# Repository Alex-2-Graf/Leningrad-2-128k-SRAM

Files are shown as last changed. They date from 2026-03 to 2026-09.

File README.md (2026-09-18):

# Leningrad-2-128k-SRAM  
  
> [English](README.en.md) | [Русский](README.md)  
  
---
  
## Leningrad-2. Russian ZX Spectrum clone. Schematics and PCB.  
  
После успешного запуска [Leningrad-2-48k](https://github.com/Alex-2-Graf/LENINGRAD-2-48k) и с учётом предложений сообщества  
было принято решение использовать в проекте статическую память вместо динамической.  
Пришлось существенно переделать узел обращения к памяти.  
Заодно было реализовано расширение до 128K без использования внешних плат.  
Также на освободившемся месте удалось разместить два чипа YM2149F,  
тем самым получив «из коробки» Turbo Sound от NedoPC.  
Также был добавлен арбитр IORQ.  
  
В результате на свет появился «Ленинград 2 NEXT 128K + TS 2025».  
  
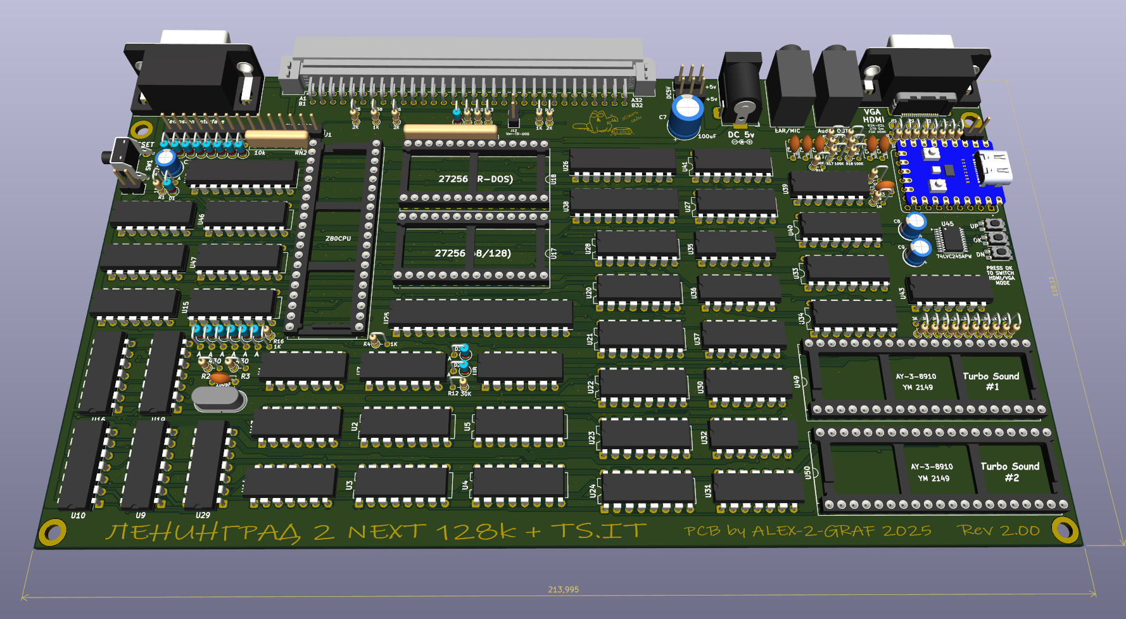
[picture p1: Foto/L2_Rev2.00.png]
  
  
После сборки и отладки были устранены мелкие недостатки.  
Также по настойчивым просьбам друзей проект получил новое название "Аврора".  
  
Свет увидела новая версия [iBOM 2.01](Export/Leningrad%202%20128k%20SRAM%202.01%202025.html)   [Схема](Export/Leningrad%202%20128k%20SRAM%202.01%202025.pdf)   [Gerber](Gerber/Leningrad%202%20128k%20SRAM%202.01%202025%20gerber%20made%20in%20Italy.zip)  
  
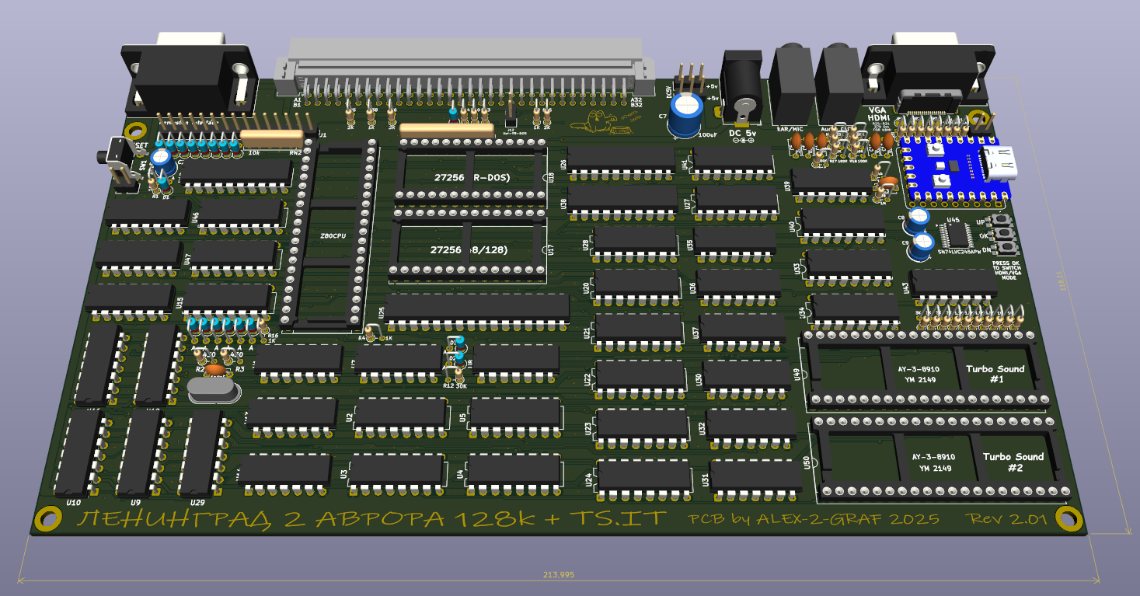
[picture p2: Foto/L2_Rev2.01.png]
  
  
Не обошлось и без курьёза.  
По настойчивой просьбе производителя плат  
пришлось изменить надпись с "Made in" на "Designed in" ;)  
  
После сборки всё заработало без нареканий.  
  
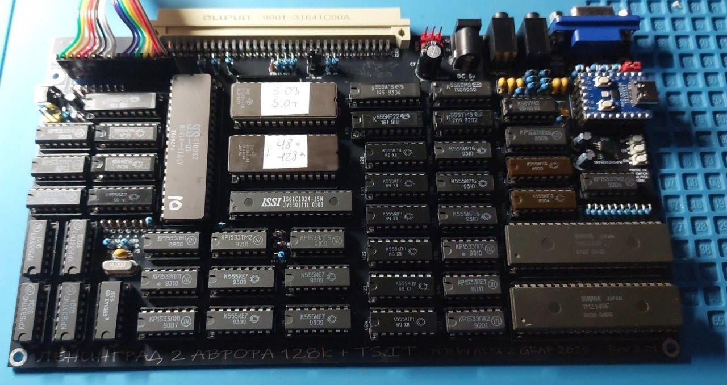
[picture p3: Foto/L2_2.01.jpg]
  
  
Перед выпуском следующей версии были добавлены индикатор питания и исправлен порт джойстика.  
В производство отправилась версия [iBOM 2.02](Export/Leningrad%202%20128k%20SRAM%202.02%202025.html)   [Схема](Export/Leningrad%202%20128k%20SRAM%202.02%202025.pdf)   [Gerber](Gerber/Leningrad%202%20128k%20SRAM%202.02%202025%20Gerber.zip)  
  
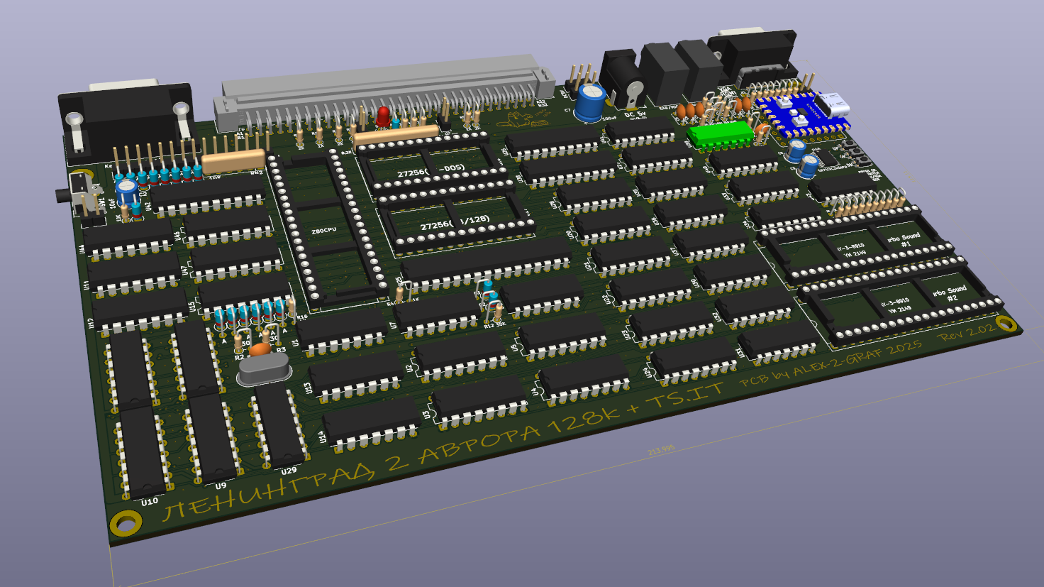
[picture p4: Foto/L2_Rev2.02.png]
  
  
Также был выпущен переходник на Немо и ZX-bus [Gerber](Gerber/L2_NS_Rev_1_1_Gerber.zip)  
  
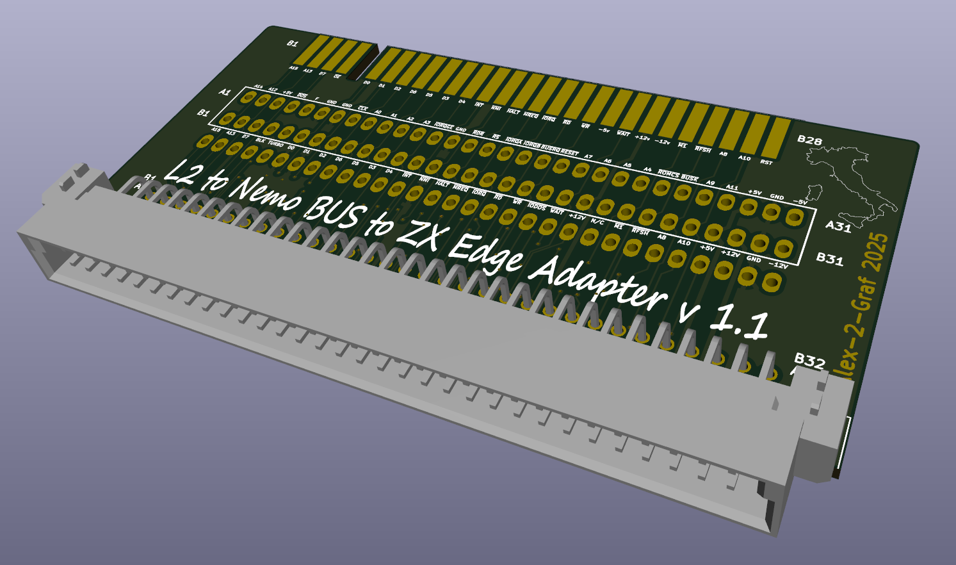
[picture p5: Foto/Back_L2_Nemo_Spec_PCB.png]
  
  
Его отличие от предыдущего заключается в использовании сигнала /IORQ-GE по прямому назначению.  
Если раньше /IORQ-GE приходил на A19 (+beta),  
то теперь он приходит на A17.  
То есть в переходнике первой ревизии необходимо отрезать дорожку от A19 и припаять её к A17.  
Всё! Вы стали обладателем второй ревизии.  
  
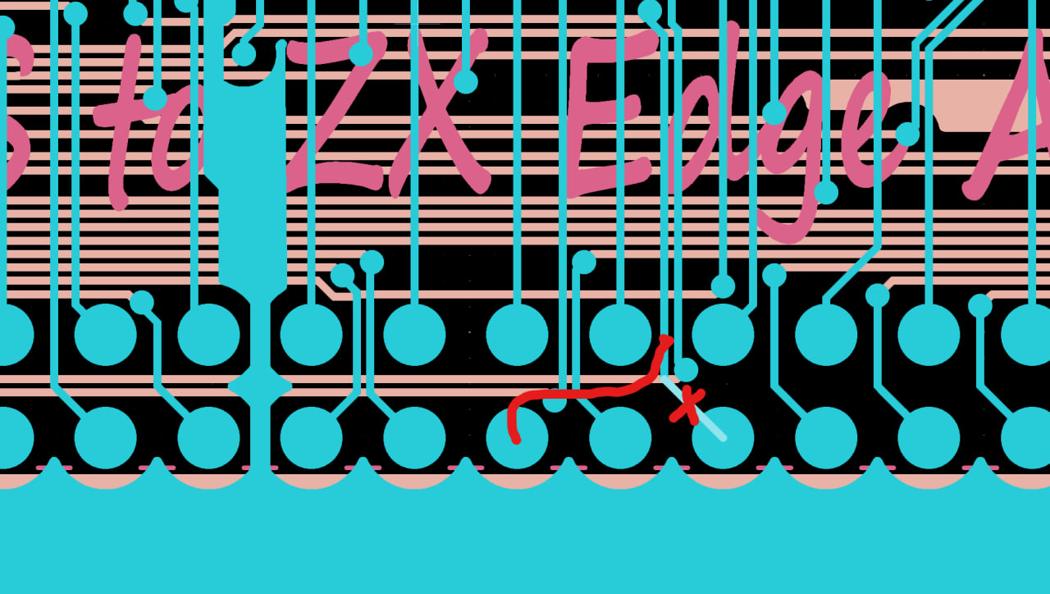
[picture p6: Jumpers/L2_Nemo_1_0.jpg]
  
  
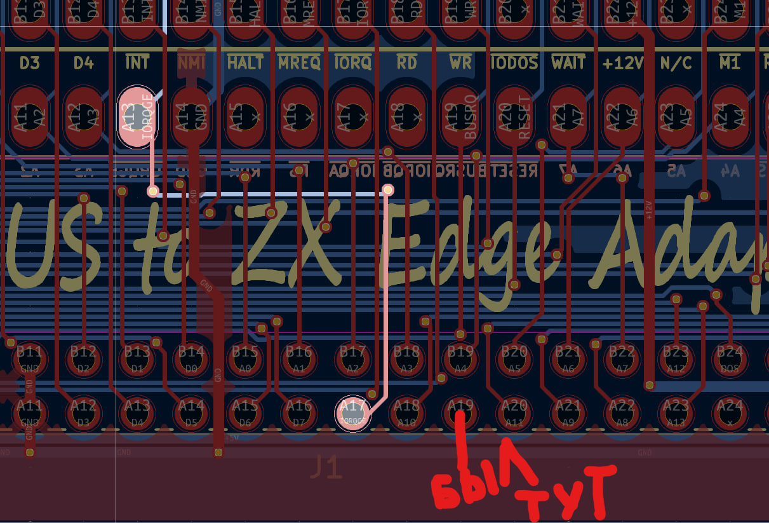
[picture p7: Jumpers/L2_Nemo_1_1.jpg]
  
  
Ну и в связи с тем, что у нас теперь есть полноценный арбитр, появилась возможность  
добавить и плату расширения слотов до 3-х Немо и одного ZX-bus [iBOM Ёлка](Export/Back_L2_Nemo_x3_Spec_Ver2.1.html)   [Схема](Export/Back_L2_Nemo_x3_Spec_Ver2.1.pdf)   [Gerber](Gerber/Back_L2_Nemo_x3_Spec_Ver2.1_gerber.zip)  
  
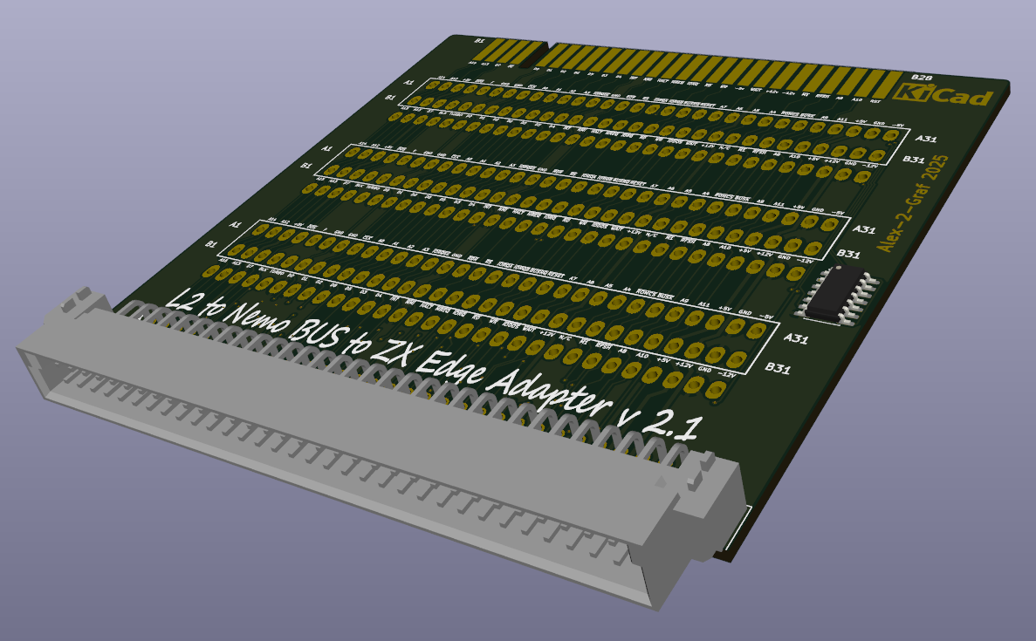
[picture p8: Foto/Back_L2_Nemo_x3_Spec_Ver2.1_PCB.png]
  
  
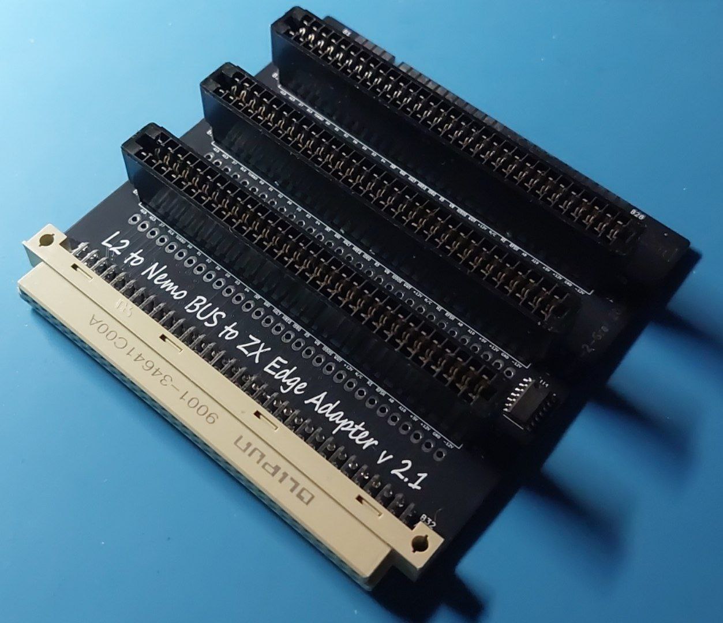
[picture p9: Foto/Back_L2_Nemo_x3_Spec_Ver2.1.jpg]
  
  
Результат оправдал ожидания.  
  
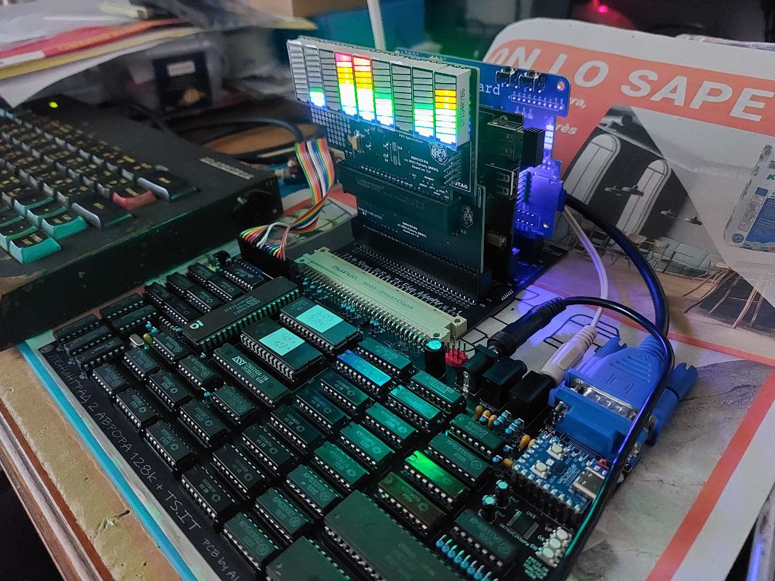
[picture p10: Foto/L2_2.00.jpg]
  
  
После небольших раздумий, была разведена новая плата расширения слотов.  
На ней ZX-bus заменён на разъём от Ленинграда 2.  
Также был добавлен разьём питания +5/+12в.  
[iBOM Ёлка](Export/Back_L2_Nemo_x3_L2.html)   [Схема](Export/Back_L2_Nemo_x3_L2.pdf)   [Gerber](Gerber/Back_L2_Nemo_x3_L2_gerber.zip)  
  
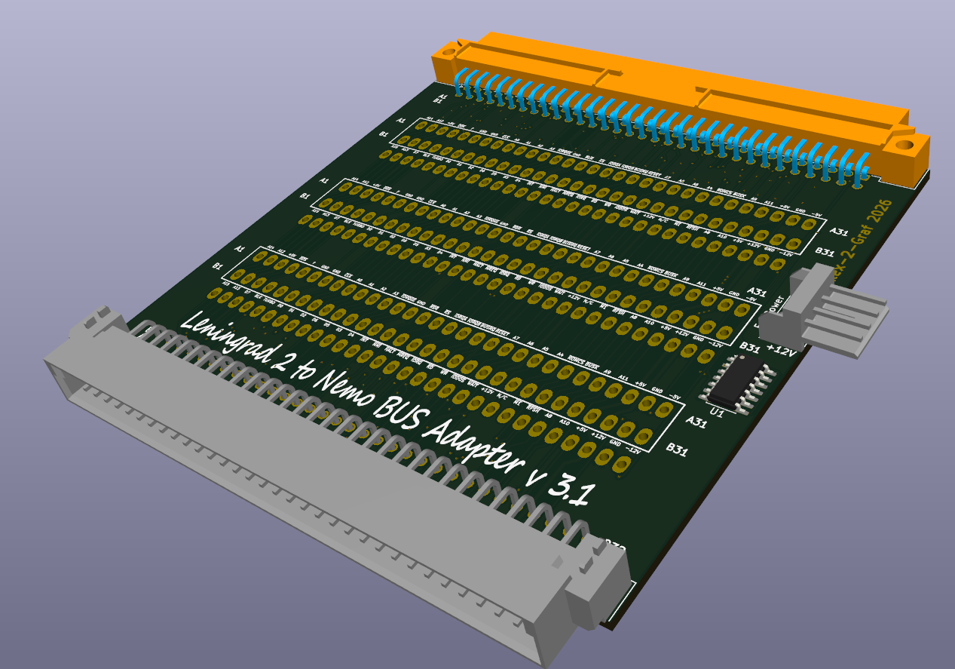
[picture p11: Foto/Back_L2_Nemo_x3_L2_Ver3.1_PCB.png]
  
  
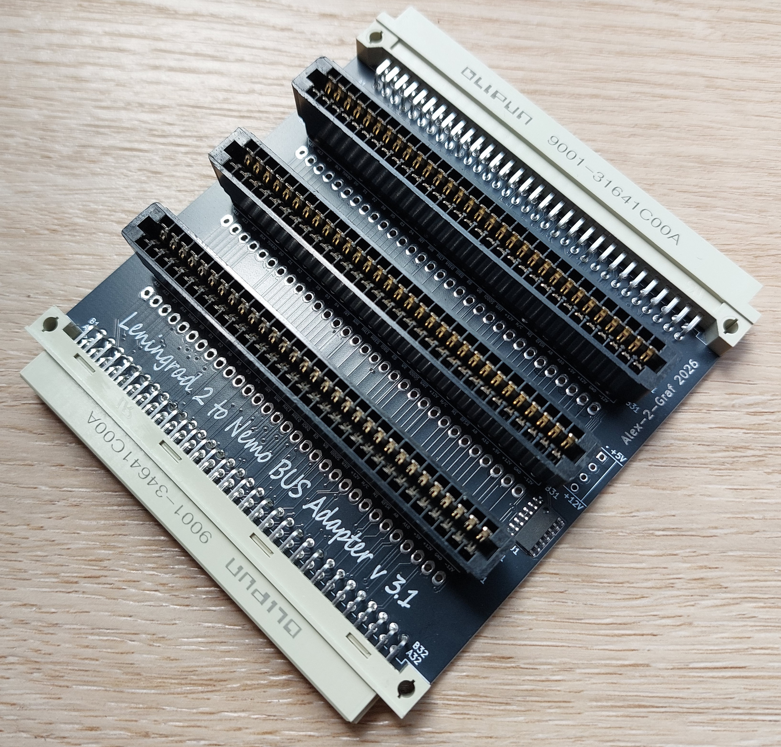
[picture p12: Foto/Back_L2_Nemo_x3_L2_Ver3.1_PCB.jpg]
  
  
И вот результат.  
  
  
  
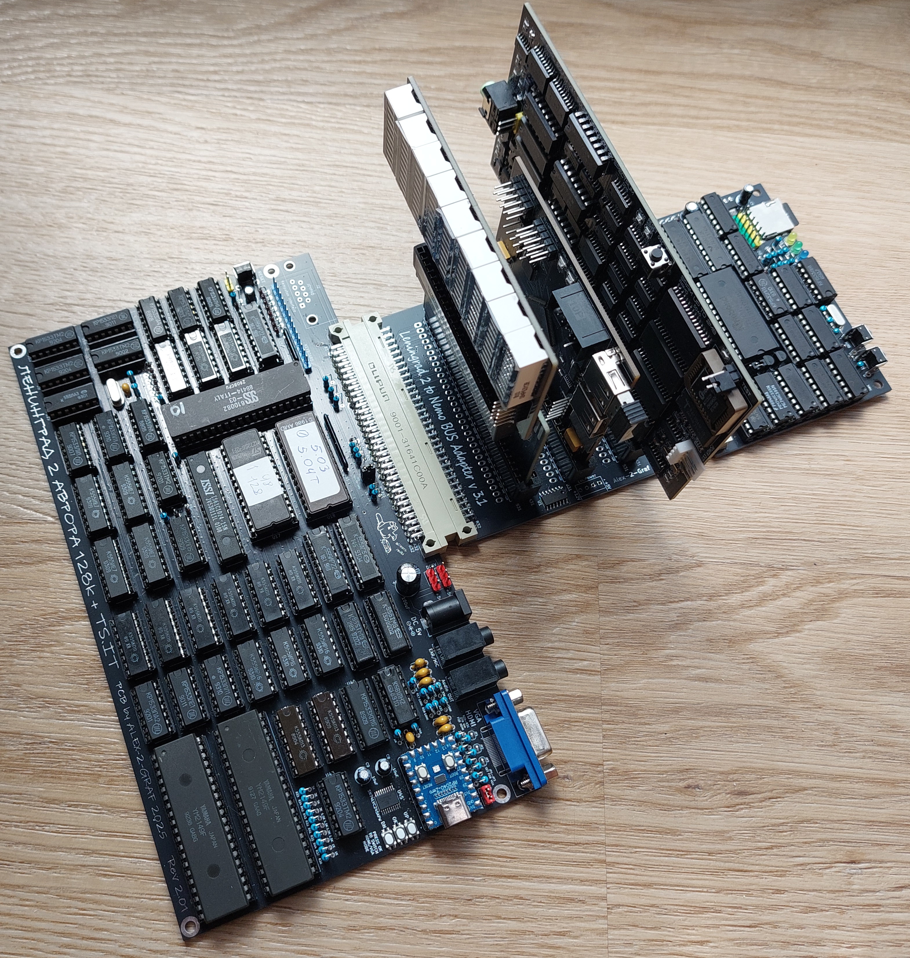
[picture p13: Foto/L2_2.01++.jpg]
  
  
При этом платы ZX-bus можно подключать через переходники.  
[Первый](Gerber/Nemo2ZX_BUS_v1.zip)   [Второй](Gerber/Nemo2ZX_BUS_v2.zip)  
  
  
  
---
  
## Клавиатура  
  
Так же были разведены 2 версии плат для клавиатуры.  
  
Для размещения в корпусе.  
[Gerber](Gerber/ZX-Keyboard_Gerber.zip)  
  
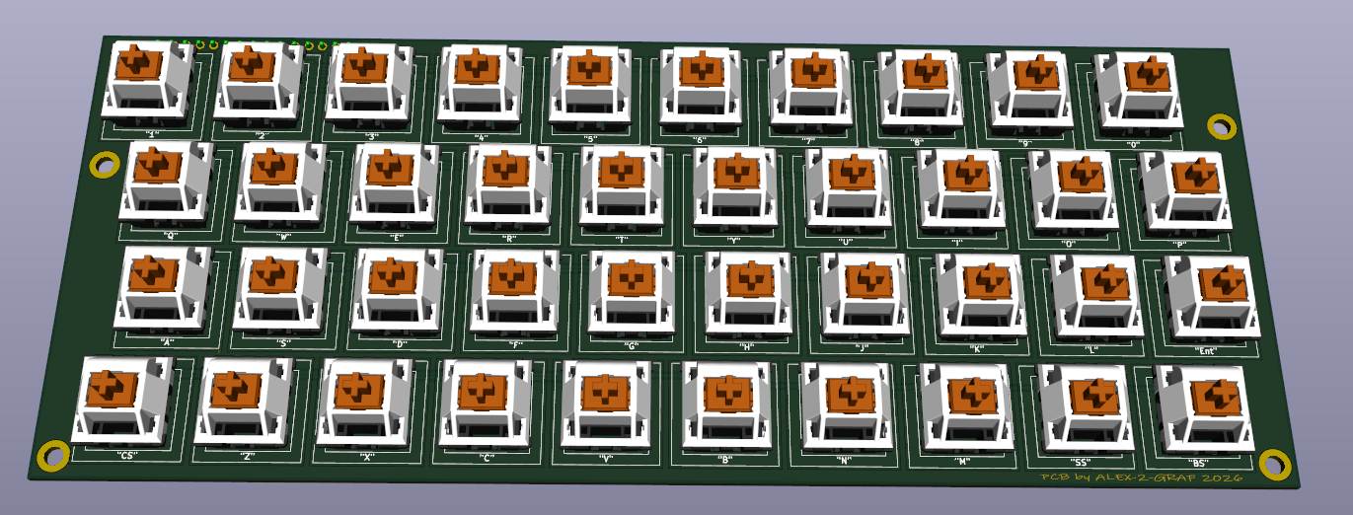
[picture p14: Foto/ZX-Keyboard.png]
  
  
Либо вторым этажём.  
[Gerber](Gerber/L2-40Key_gerber.zip)  
  
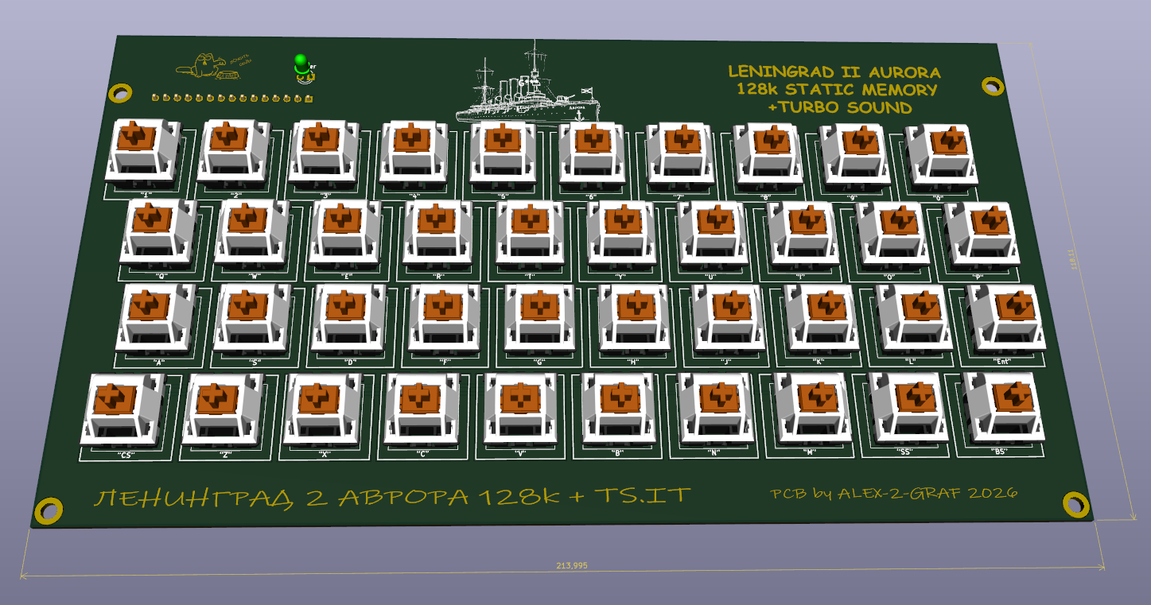
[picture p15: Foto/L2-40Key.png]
  
  
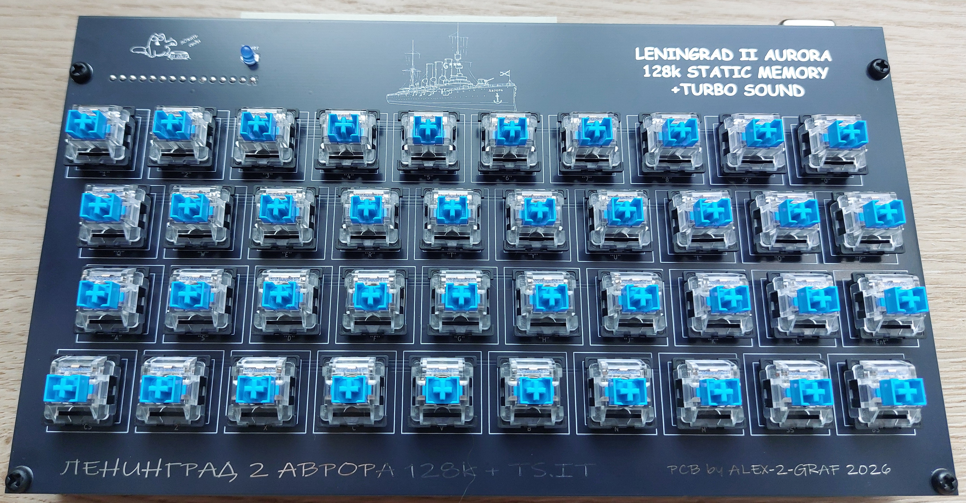
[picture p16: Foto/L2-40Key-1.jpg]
  
  
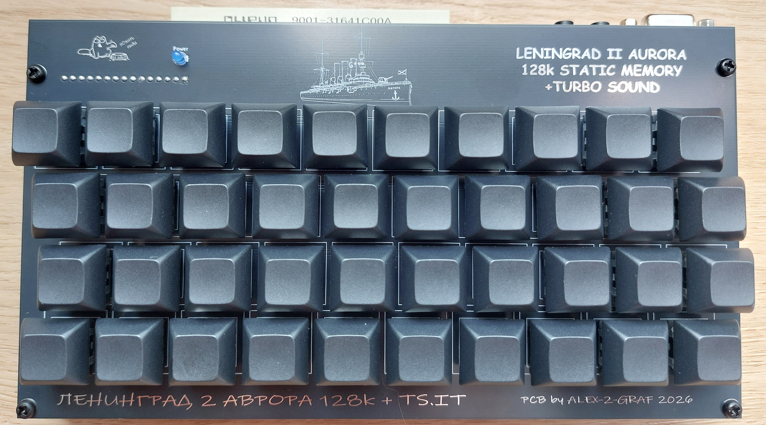
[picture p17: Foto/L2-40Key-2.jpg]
  
  
Добавлены 2 платы клавиатур для кнопок ReDragon-MX-ZT02 и ReDragon_Slim_ZT04  
[Gerber](Gerber/L2-40Key-slim-GERBER.zip)  
  
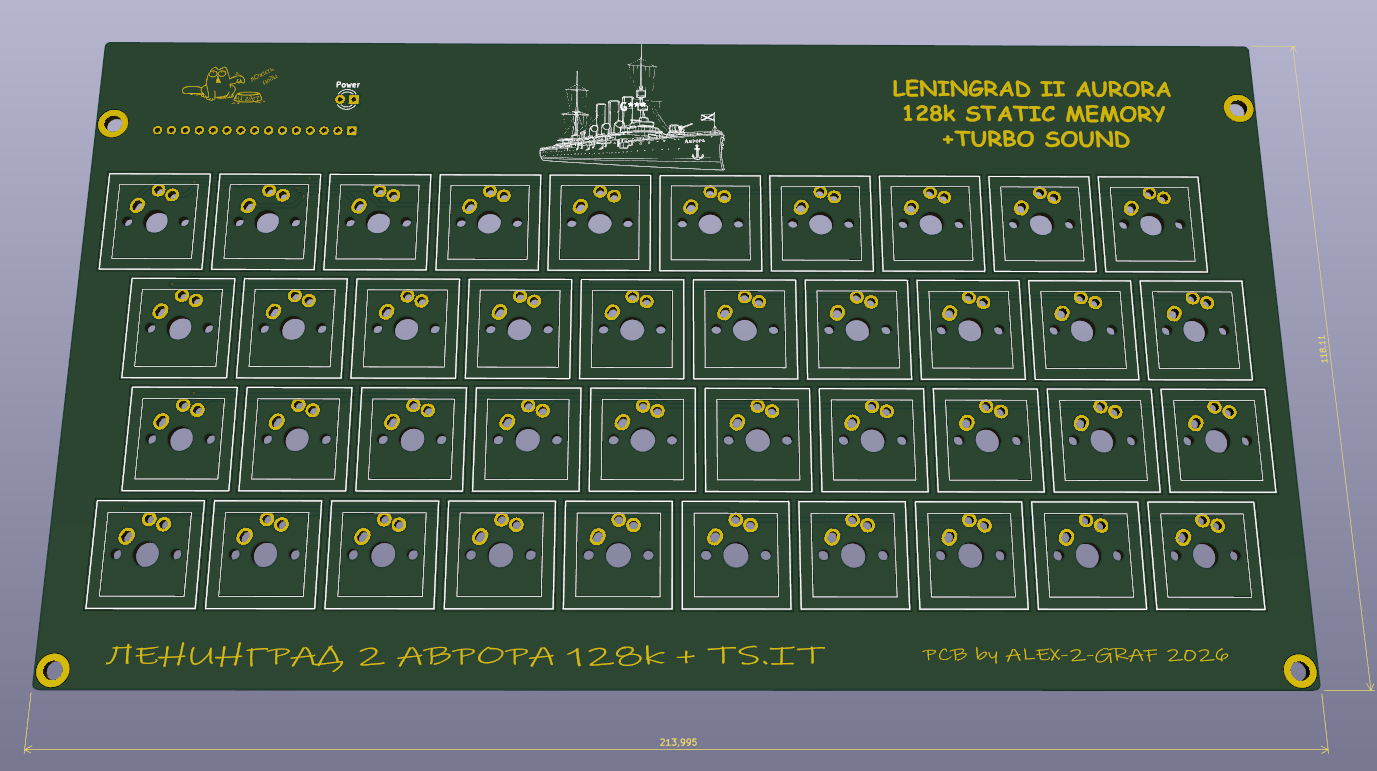
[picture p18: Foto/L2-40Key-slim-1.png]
  
  
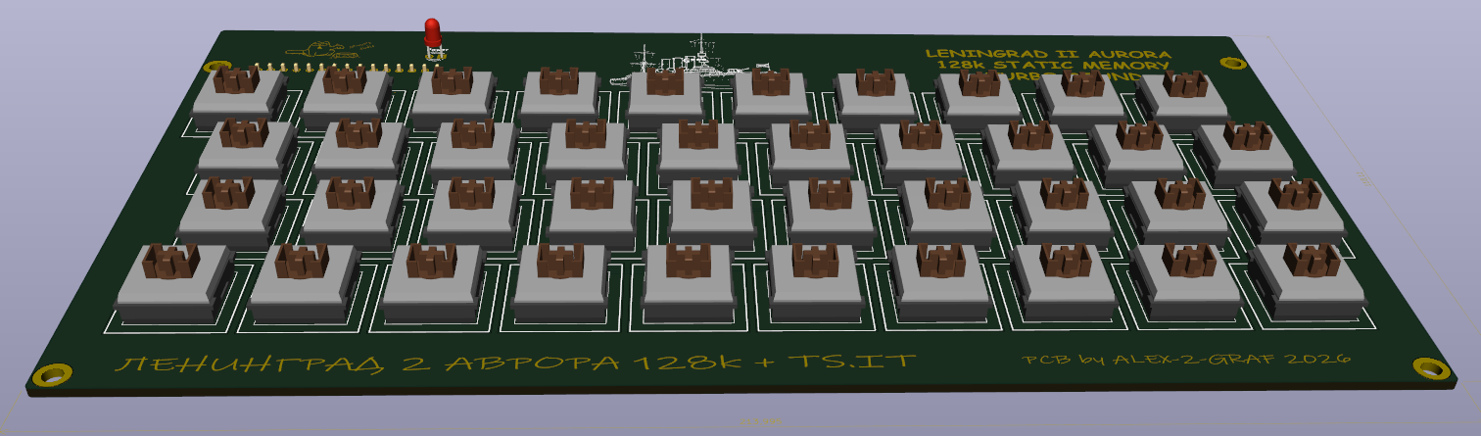
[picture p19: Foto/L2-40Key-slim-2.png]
  
  
[Gerber](Gerber/ZX-40Key-slim-Gerber.zip)  
  
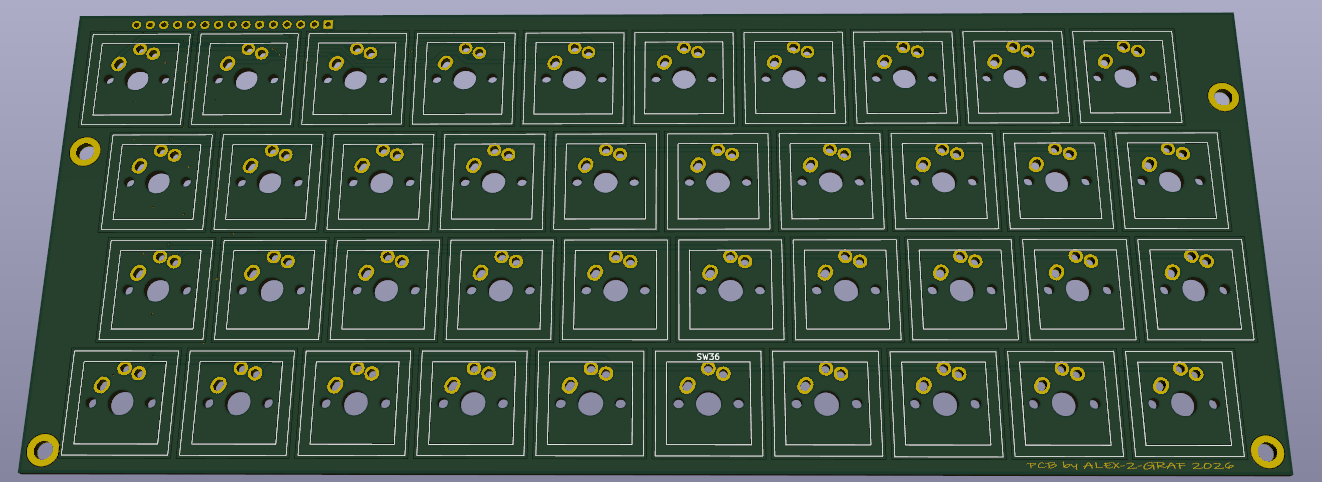
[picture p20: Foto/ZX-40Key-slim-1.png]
  
  
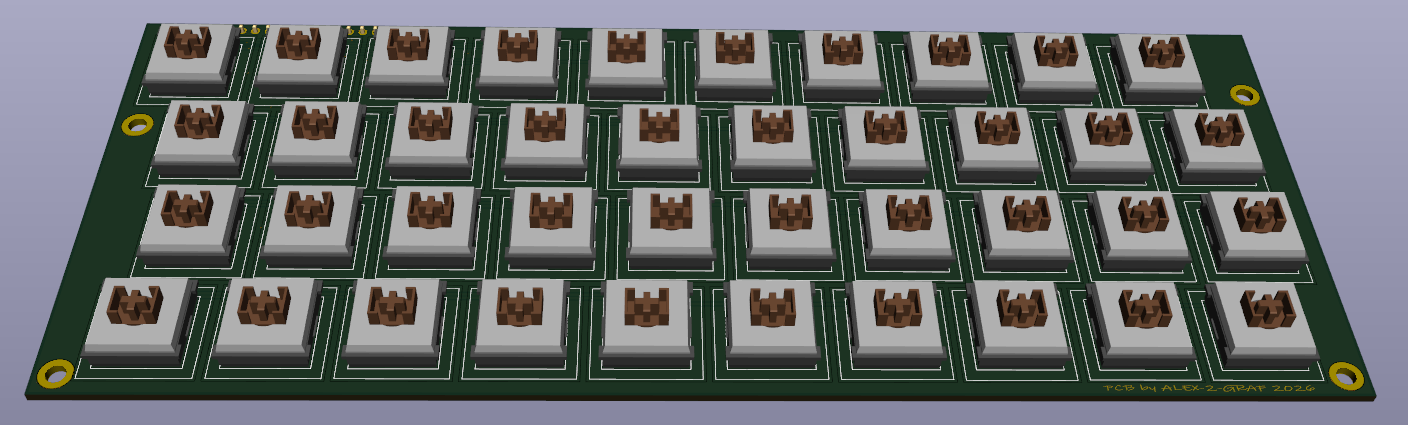
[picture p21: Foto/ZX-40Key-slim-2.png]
  
  
Для удобства запайки кнопок, можно распечатать рамку.  [Файл для печати](Export/AuroraKeys.stl)  
Для маленькой платы рамка меньше. [Файл для печати](Export/AuroraKeys_small.stl)  
  
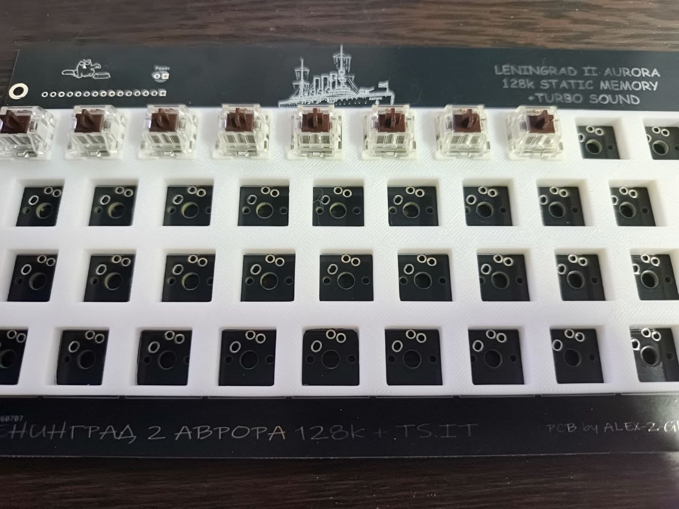
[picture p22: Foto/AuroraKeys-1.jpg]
  

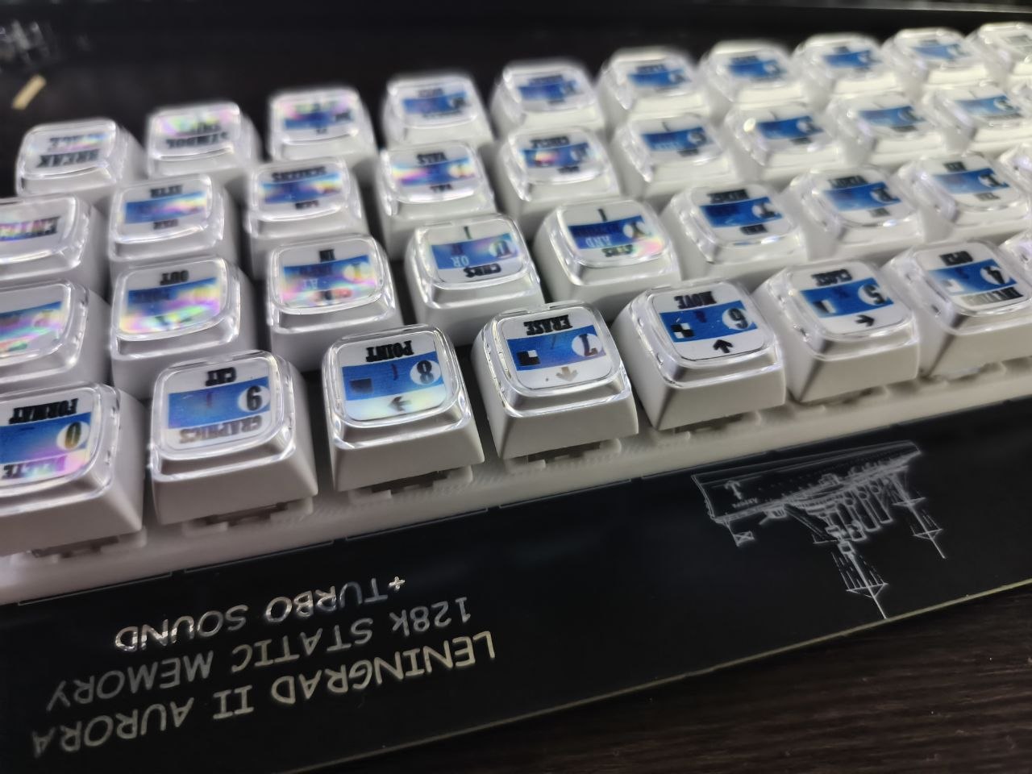
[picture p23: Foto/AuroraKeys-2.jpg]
  
  
---
  
## Корпус  
  
Корпус можно использовать от [PentoGraf-Pentagon-1024k](https://github.com/Alex-2-Graf/PentoGraf-Pentagon-1024k)  
  
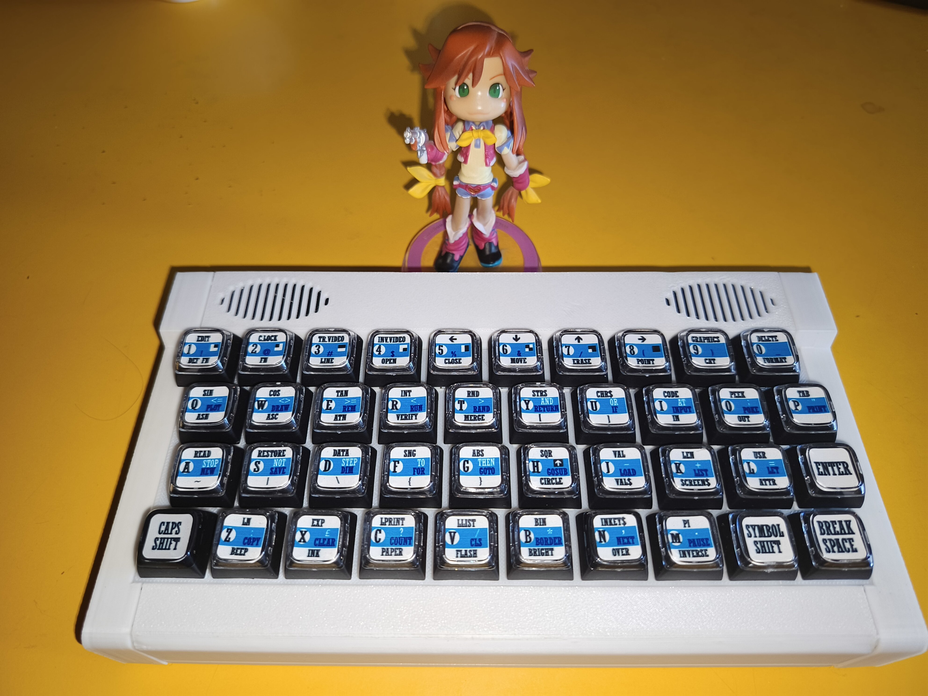
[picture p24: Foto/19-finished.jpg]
 
  
---
  
## Сборка  
  
Как правило, сборка и наладка проблем не вызывают.  
Хотя всё же проясним назначение перемычек.  
&#x20;  
JP1, JP2 и JP3 замыкаются в случае установки VGA-разъёма.  
При установке HDMI замыкать их не надо.  
Но при этом все резисторы R24-31 заменяются на 270 Ом.  
Джампер J9 необходим для снятия питания с RP2040-Zero при перепрошивке.  
  
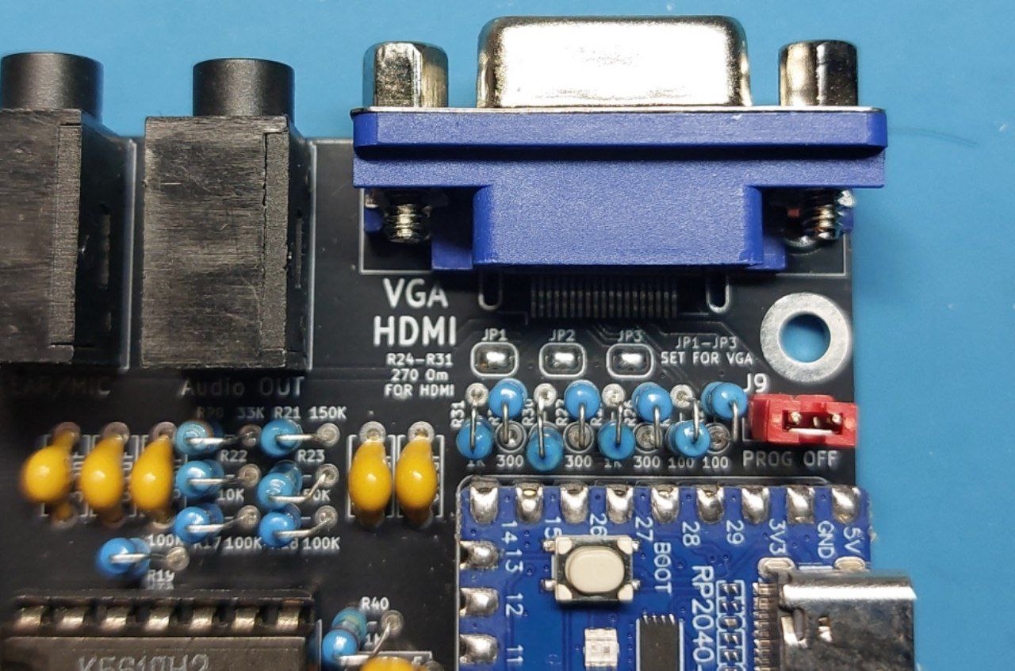
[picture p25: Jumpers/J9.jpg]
  
  
Джампер J12 необходим для выбора прошивки БДИ  
в случае установки 27256 с двумя версиями TR-DOS.  
  
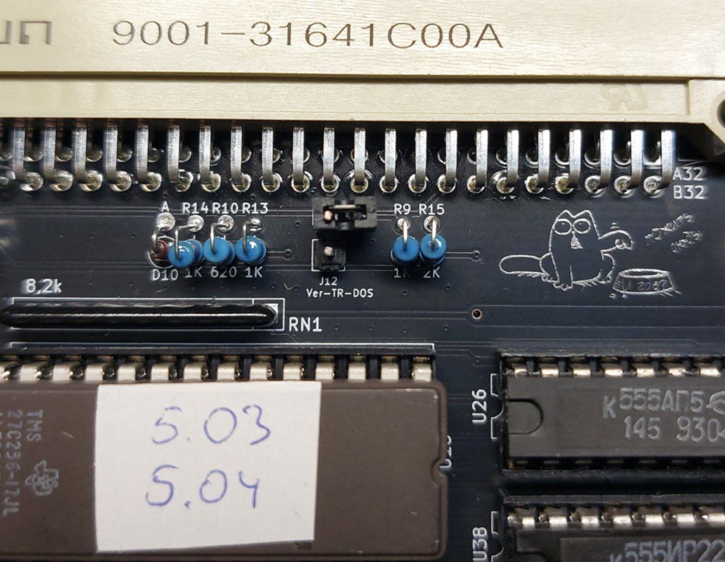
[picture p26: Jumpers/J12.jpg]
  
  
---
  
## ПЗУ  
  
ПЗУ для проекта находятся [тут](ROM)  
  
---
  
## VGA  
  
Прошивка для RP2040-Zero находится [тут](VGA)  
  
---
  
## Рекомендуемые аксессуары  
  
* [BDI-TR-DOS](https://github.com/Alex-2-Graf/Leningrad2-BDI-TR-DOS)
* [DivMMC](https://github.com/Alex-2-Graf/Leningrad2-DivMMC)
* [LGT-Turbo-Sound-emulator](https://github.com/Alex-2-Graf/LGT-Turbo-Sound-emulator)
* [ZX-EQ Nemo-bus Edition](https://github.com/Alex-2-Graf/ZX-EQ)
   
---
  
## Авторы и благодарности  
  
Alex Ekb [Алексей](https://github.com/AlexEkb4ever) — за RGB2VGA-конвертер.  
Сообществу [Scorpion ZS & Ленинград](https://t.me/zs_scorpion) и моим друзьям.  
Отдельная благодарность за советы и техпомощь HRDY [Дмитрию](https://github.com/demyanenko-d)

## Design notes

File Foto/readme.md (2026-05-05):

# Немного фото проекта.

&#x20; 

## Пробная версия

&#x20; 

  

  

&#x20; 

## Первая ревизия

&#x20; 

  

  

&#x20; 

## Вторая ревизия

&#x20; 

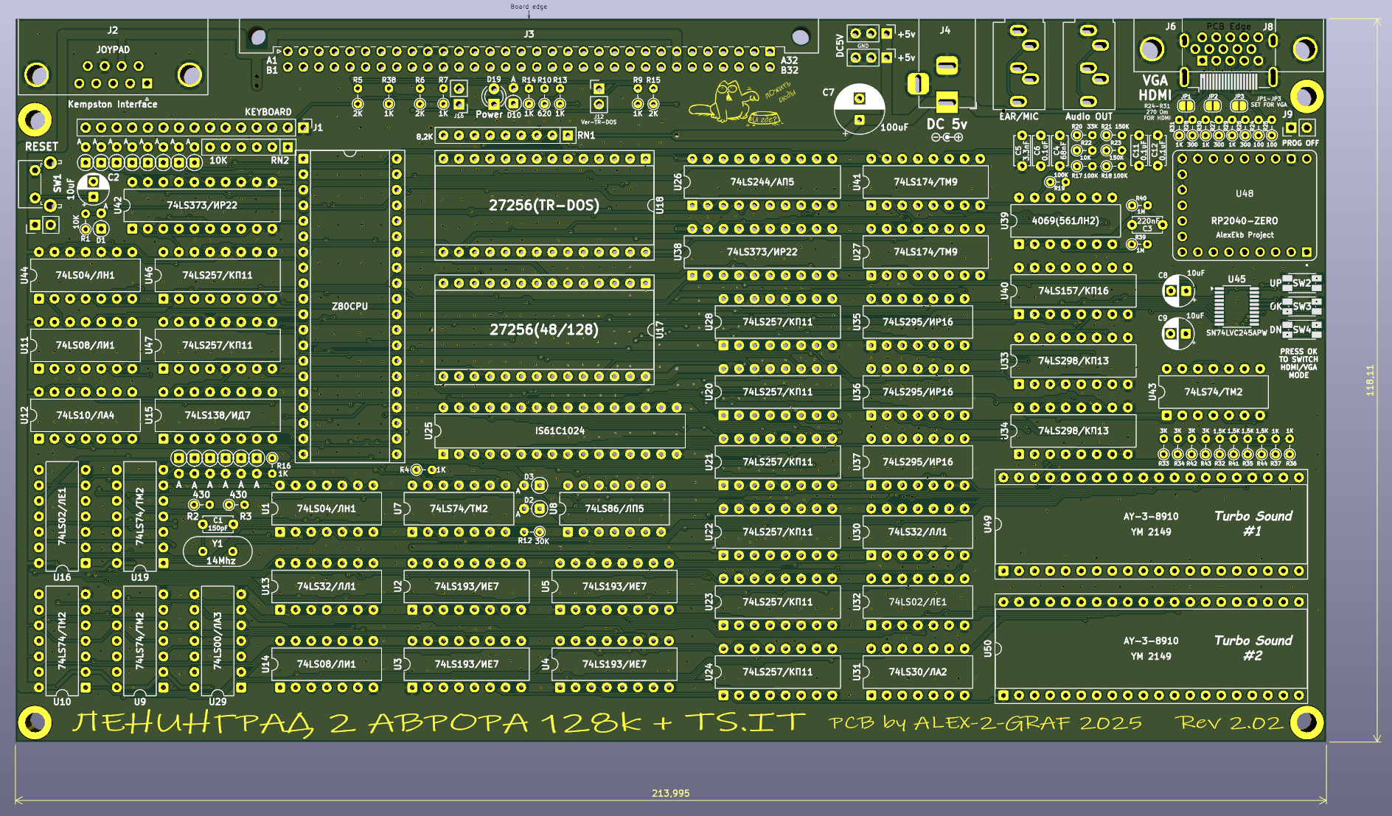
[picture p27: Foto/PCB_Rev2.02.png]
  

  

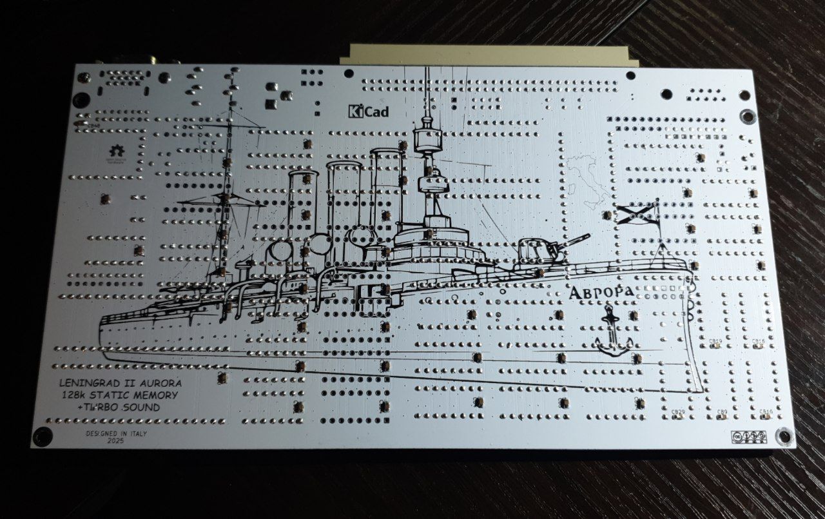
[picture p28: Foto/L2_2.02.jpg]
  

&#x20; 

## Переходник

&#x20; 

  

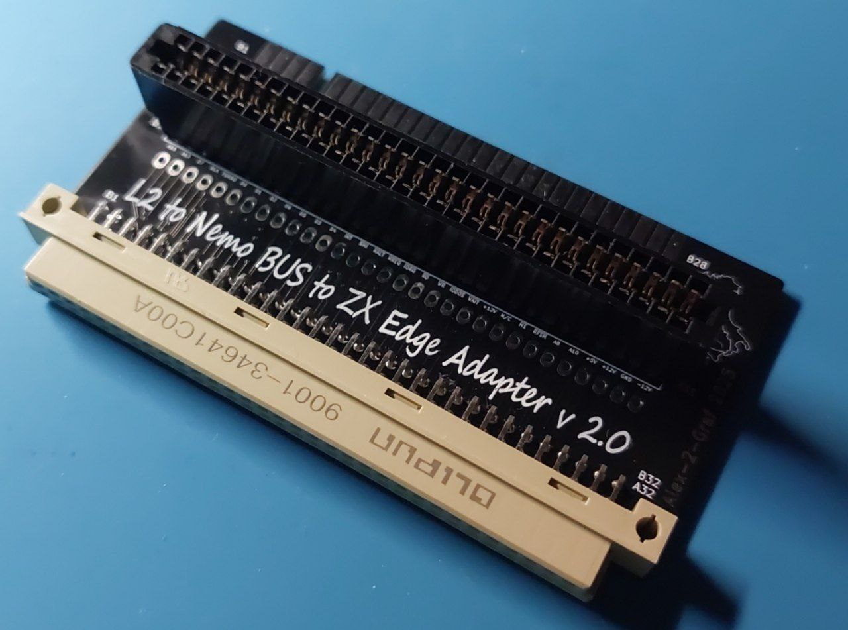
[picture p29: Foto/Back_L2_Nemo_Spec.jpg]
  

&#x20; 

## Расширитель шины

&#x20; 

  

  

&#x20; 

## Второй расширитель шины

&#x20; 

  

  

&#x20; 

## Переходник ZX-bus

&#x20; 

  

&#x20; 

## Клавиатура

&#x20; 

  



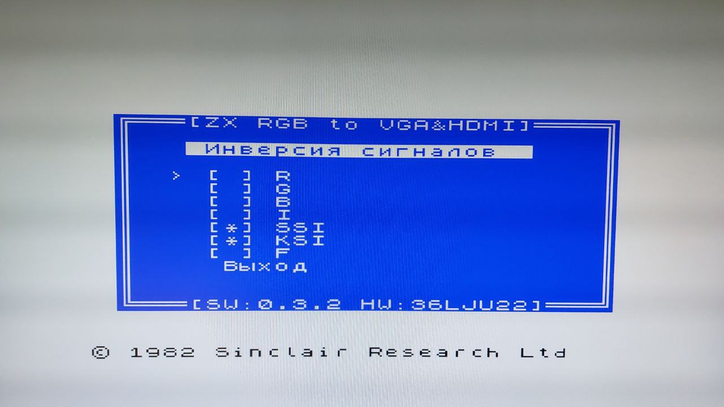
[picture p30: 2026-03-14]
VGA/VGA 3.jpg

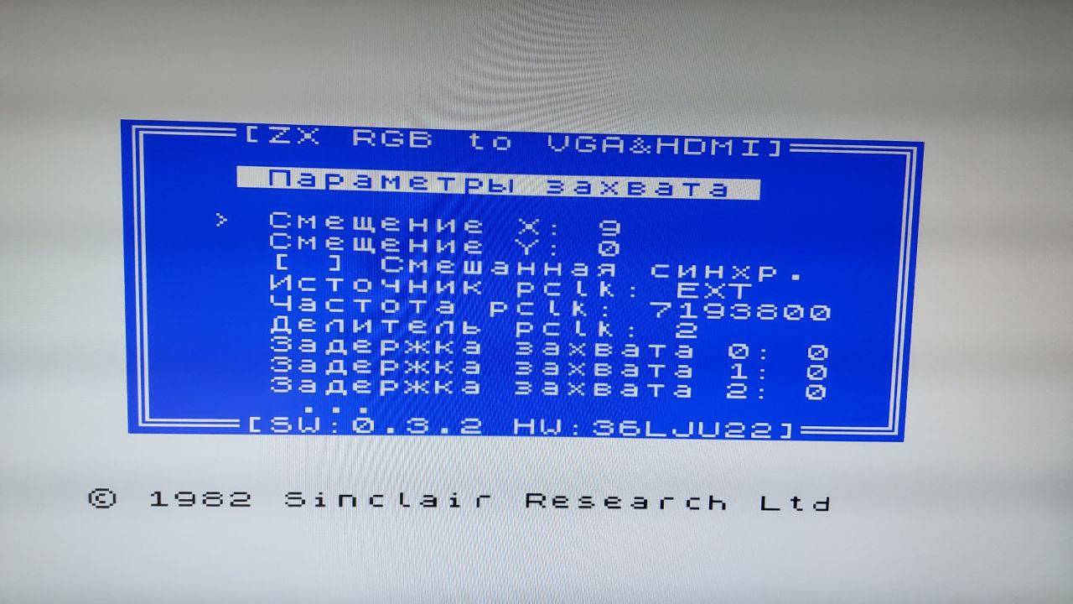
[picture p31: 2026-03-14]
VGA/VGA 2.jpg

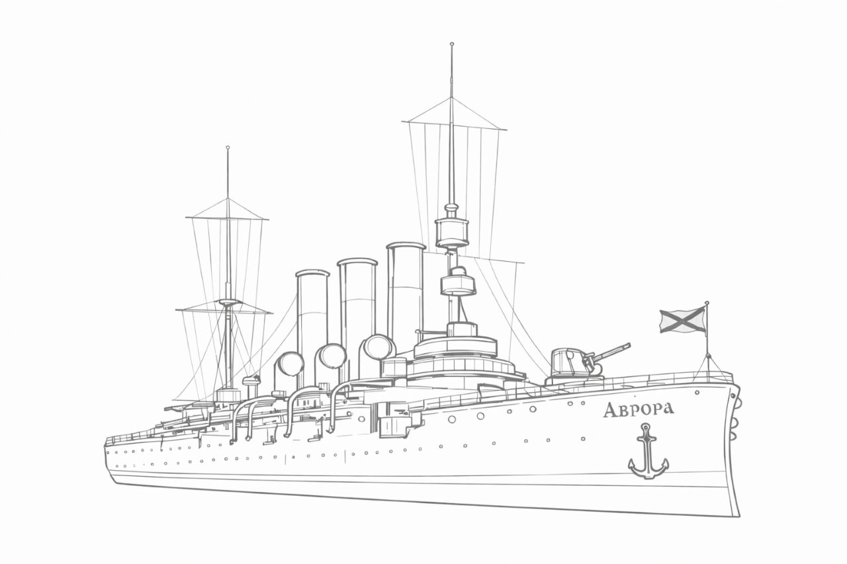
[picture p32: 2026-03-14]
Sources/photo.jpg

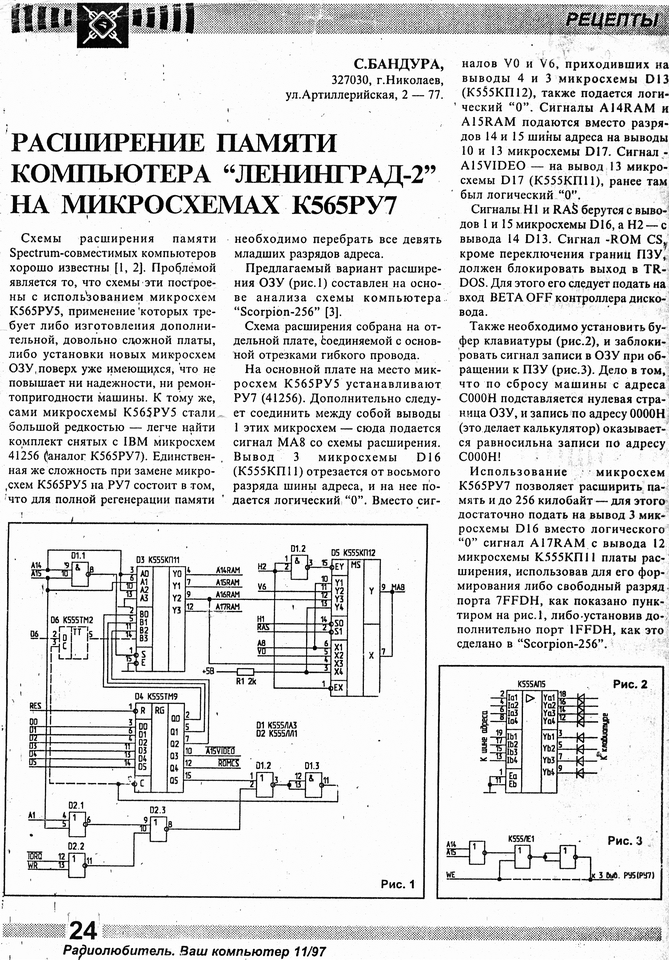
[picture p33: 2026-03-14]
Sources/rlvk971124.png

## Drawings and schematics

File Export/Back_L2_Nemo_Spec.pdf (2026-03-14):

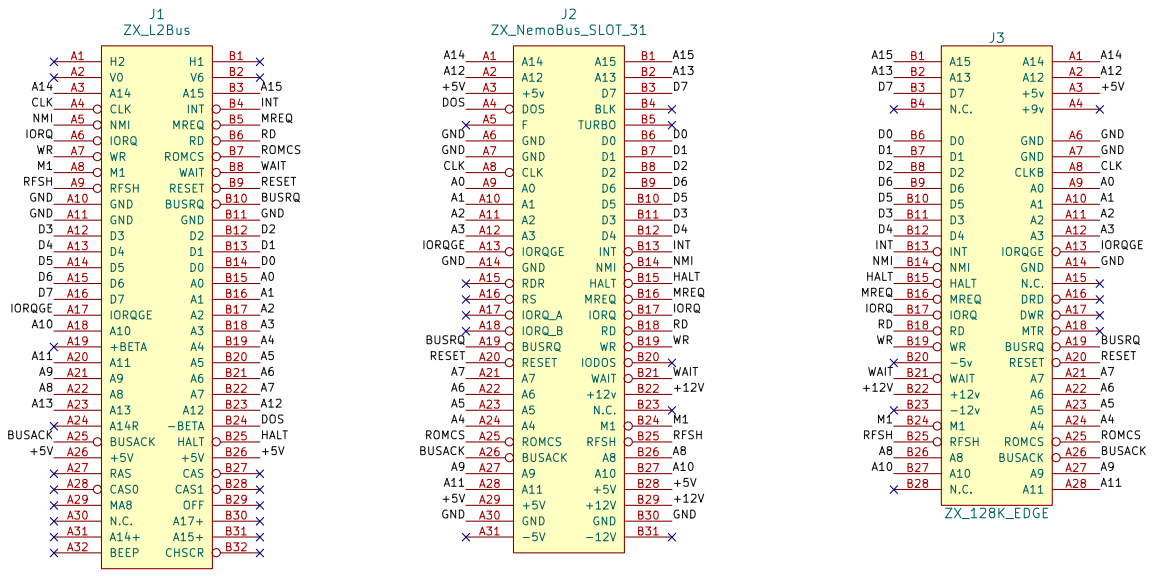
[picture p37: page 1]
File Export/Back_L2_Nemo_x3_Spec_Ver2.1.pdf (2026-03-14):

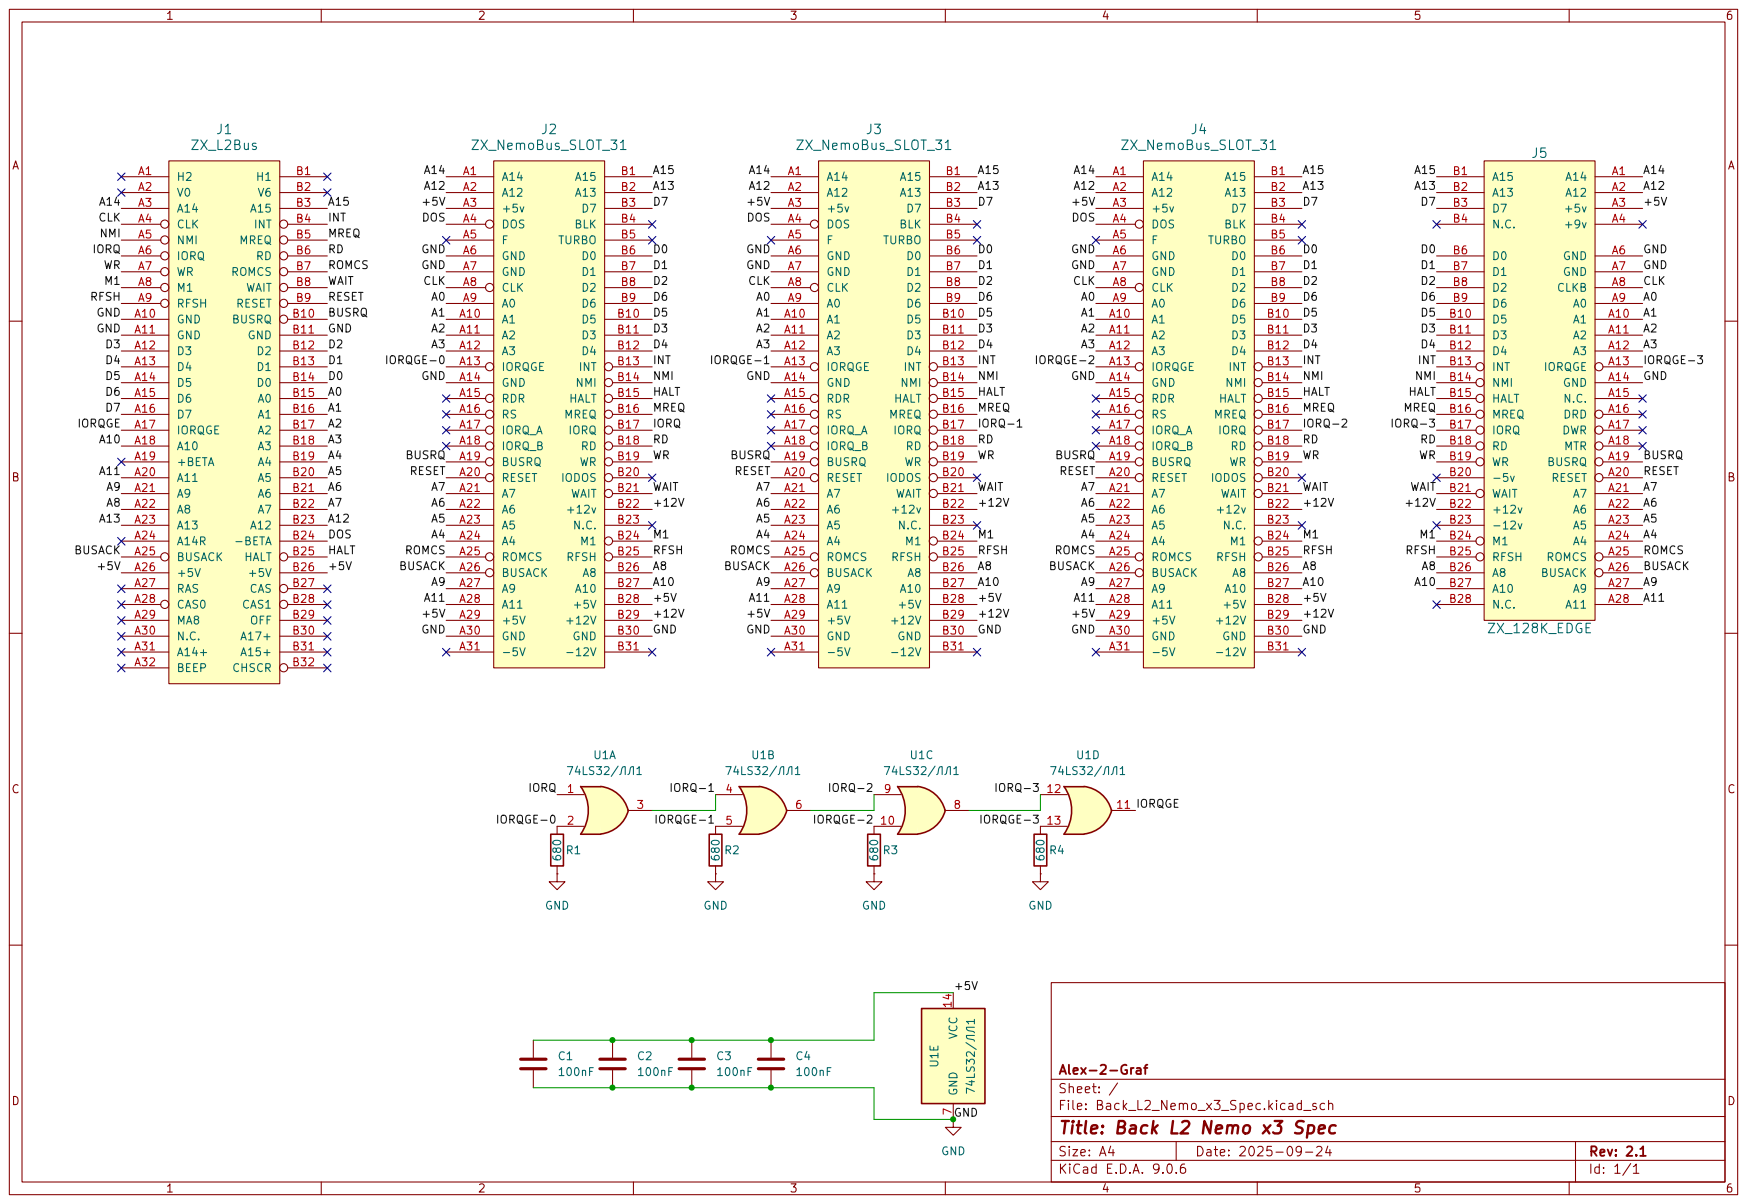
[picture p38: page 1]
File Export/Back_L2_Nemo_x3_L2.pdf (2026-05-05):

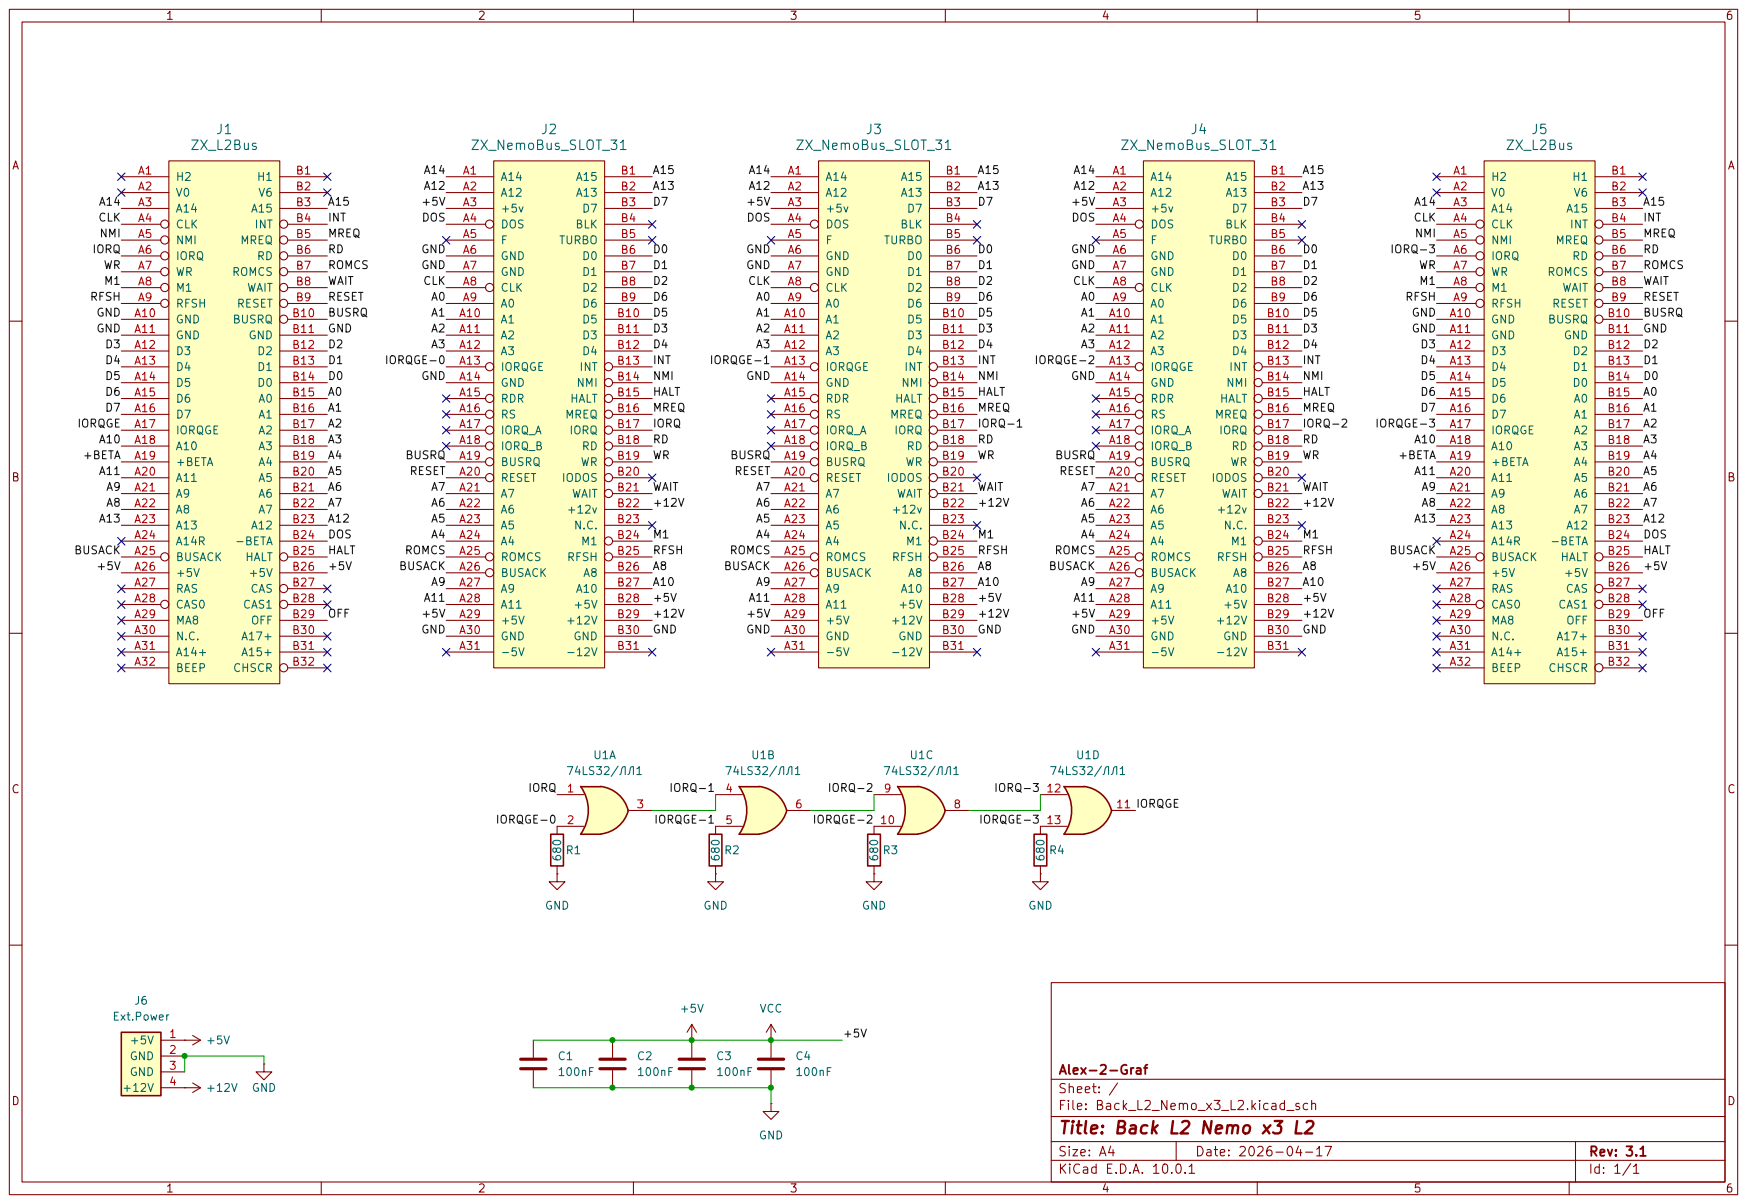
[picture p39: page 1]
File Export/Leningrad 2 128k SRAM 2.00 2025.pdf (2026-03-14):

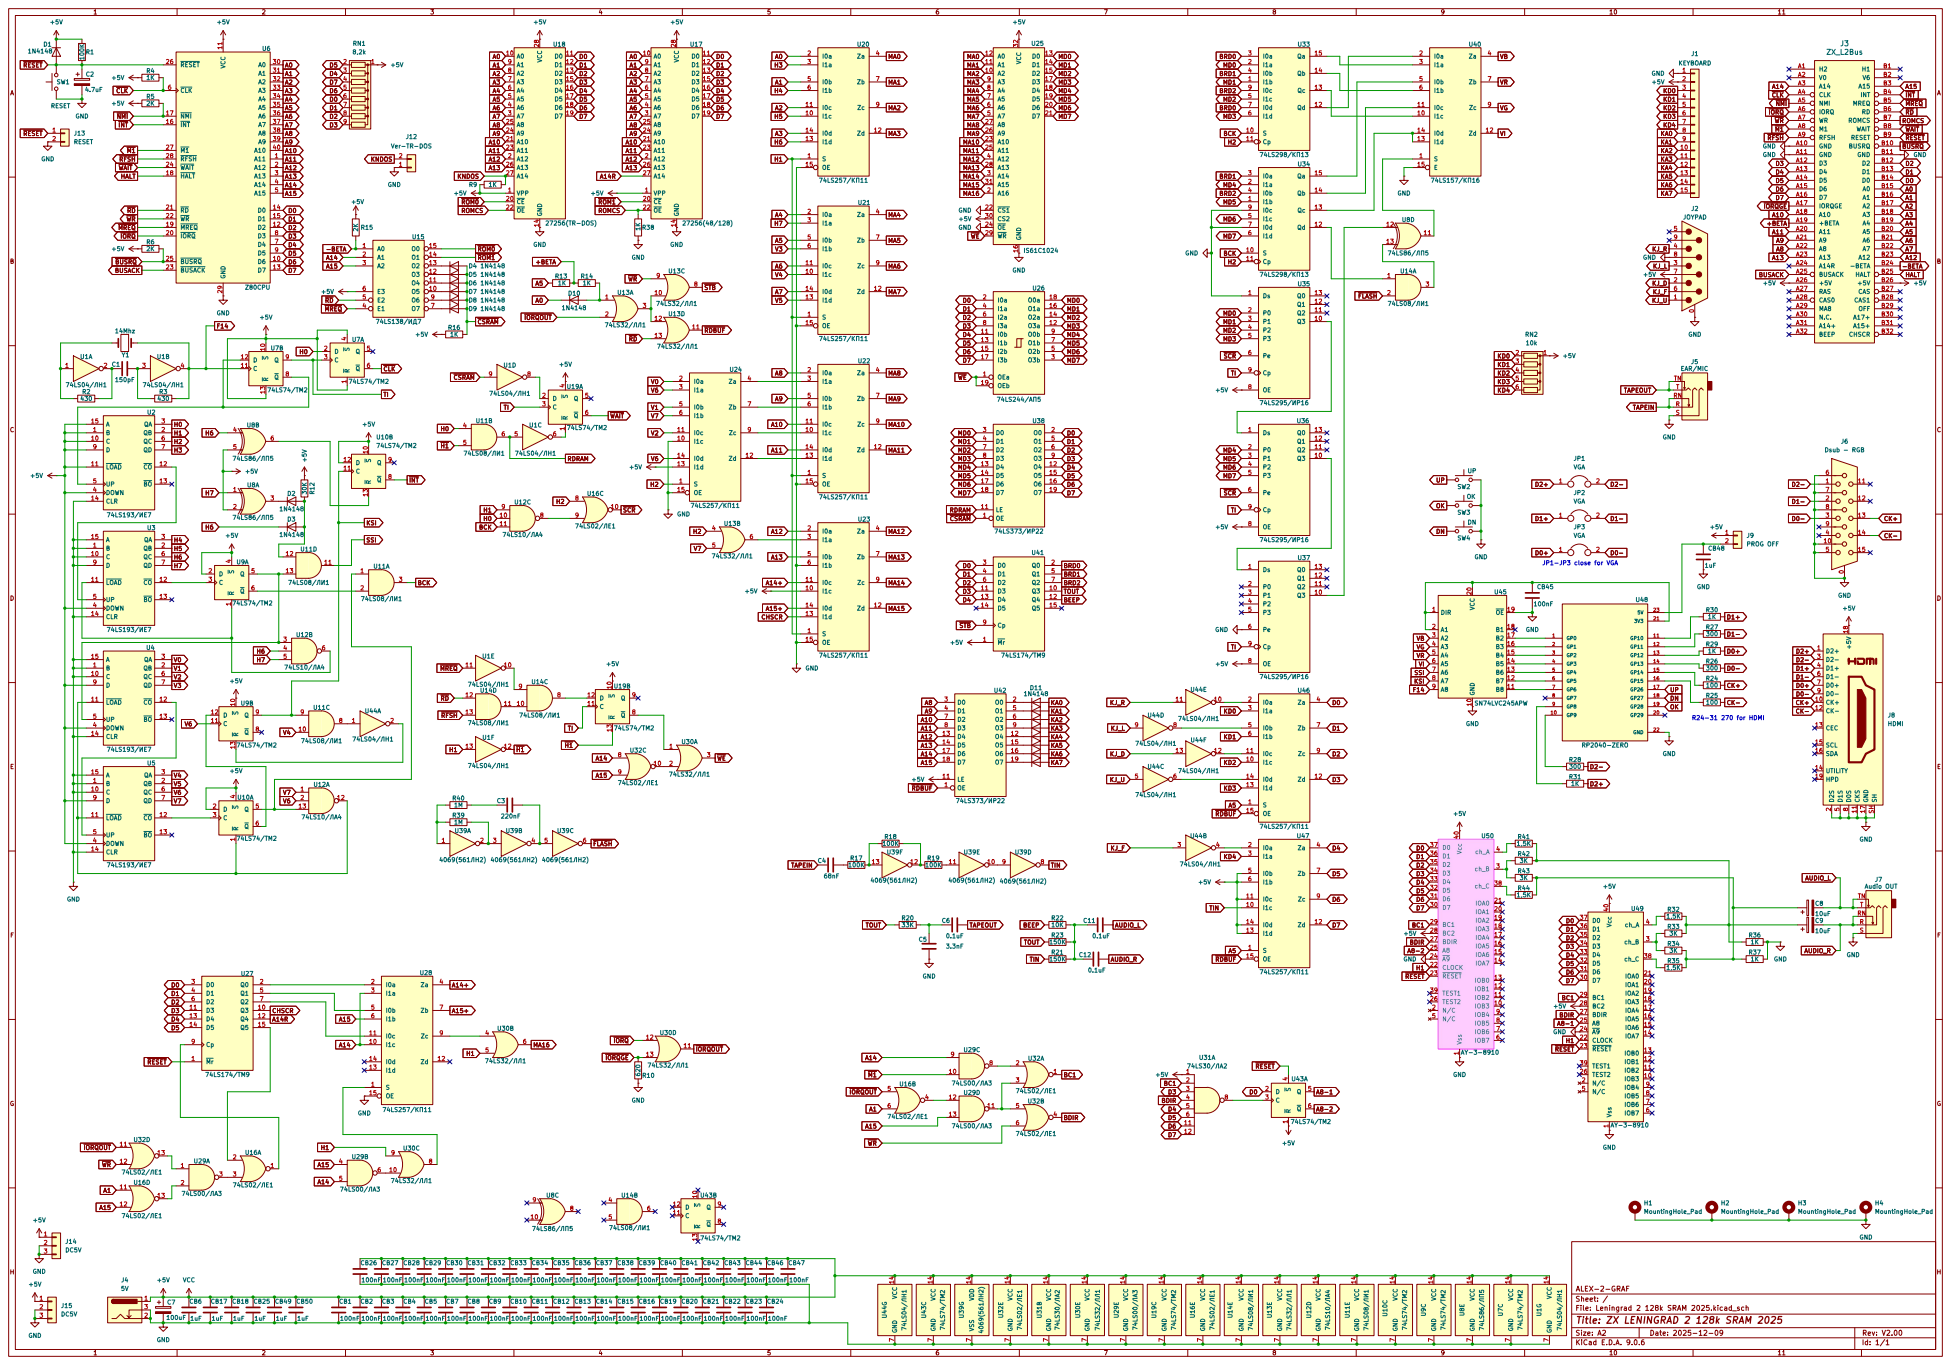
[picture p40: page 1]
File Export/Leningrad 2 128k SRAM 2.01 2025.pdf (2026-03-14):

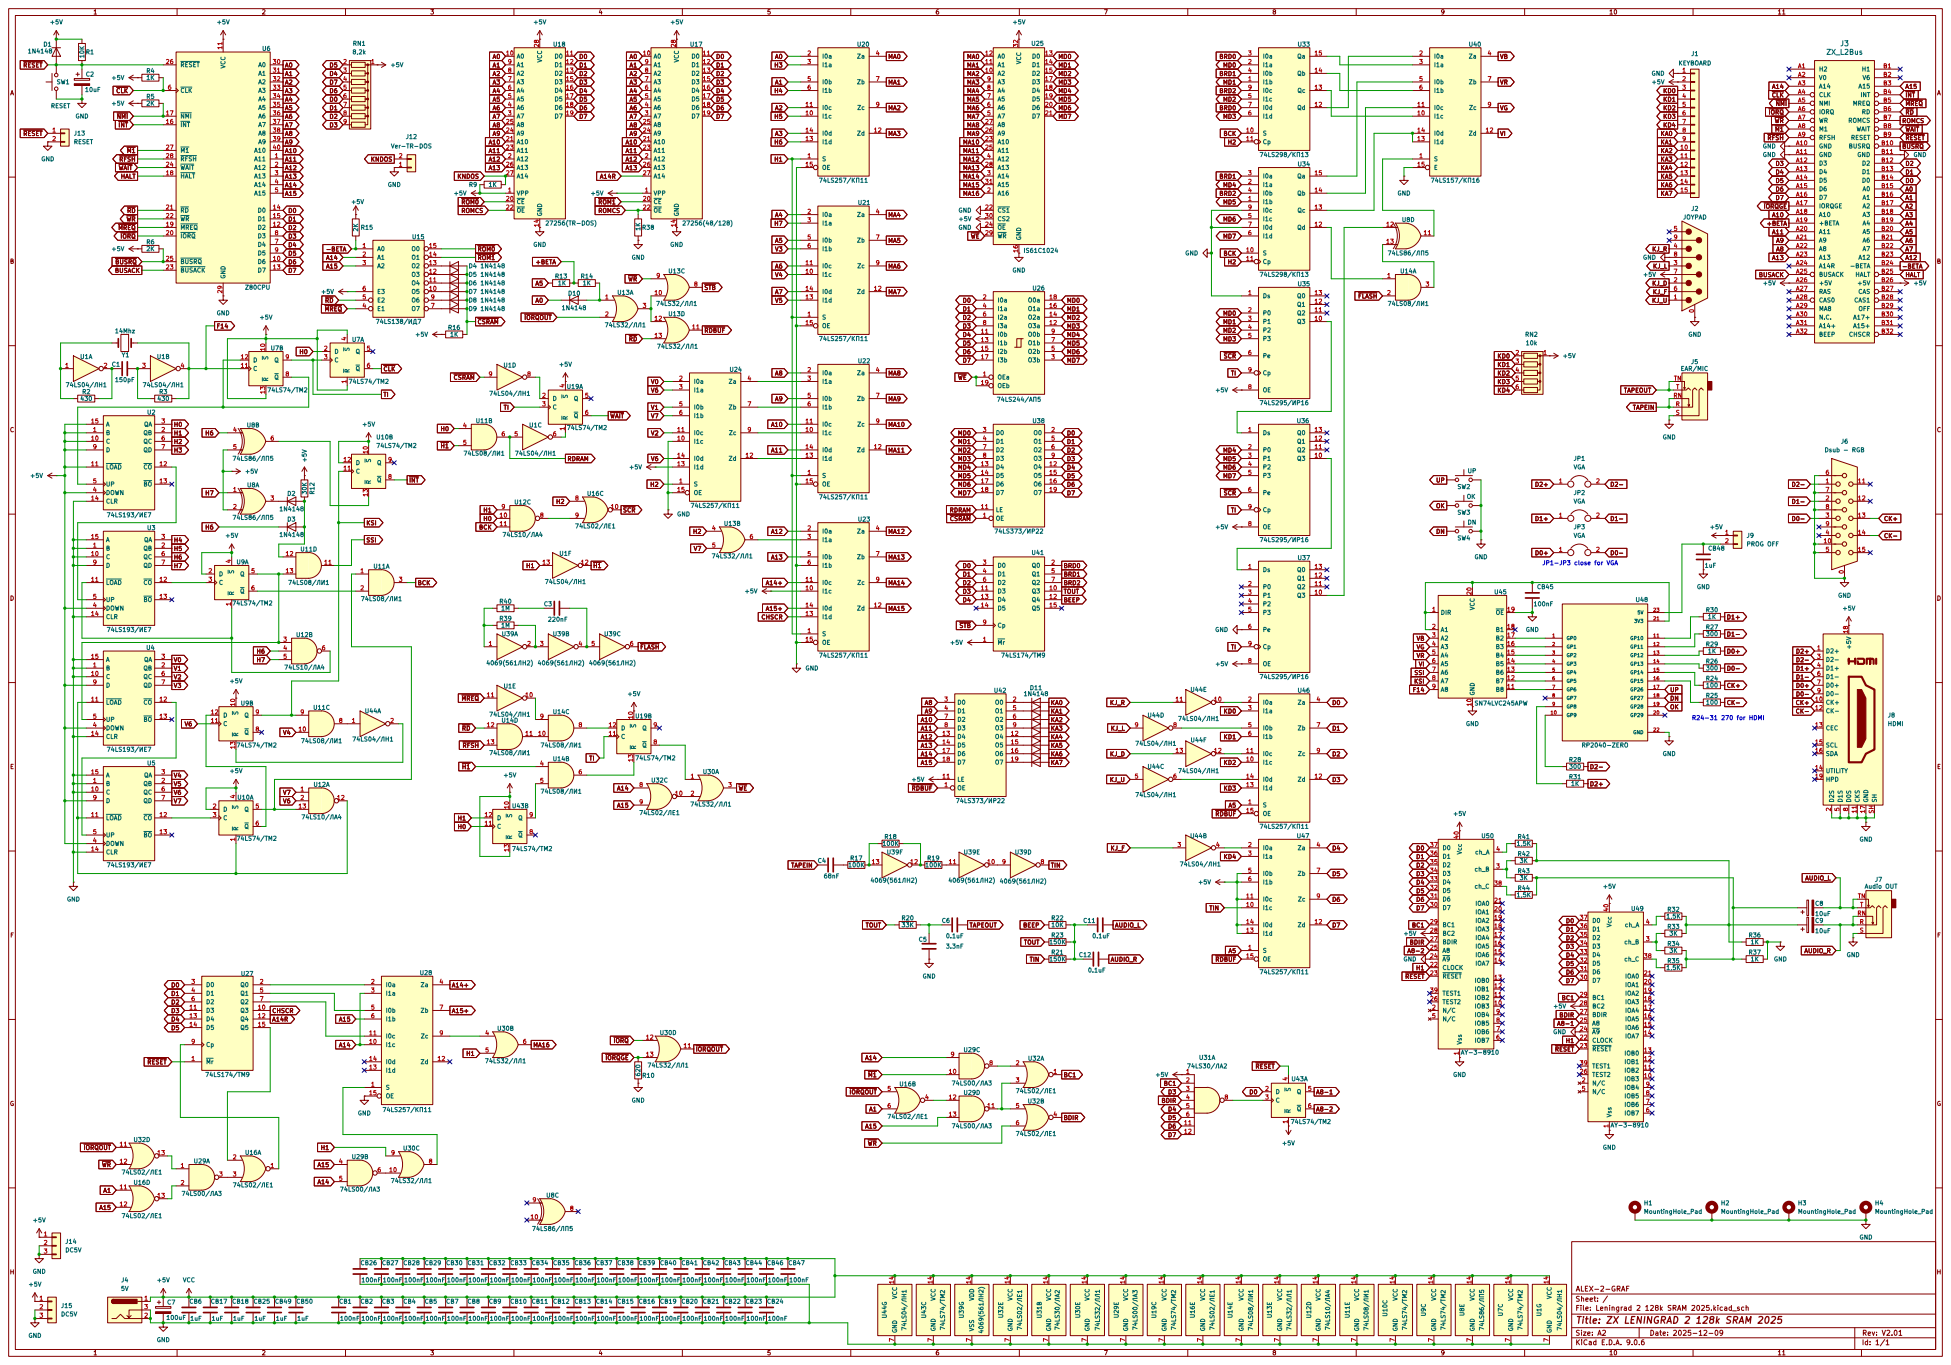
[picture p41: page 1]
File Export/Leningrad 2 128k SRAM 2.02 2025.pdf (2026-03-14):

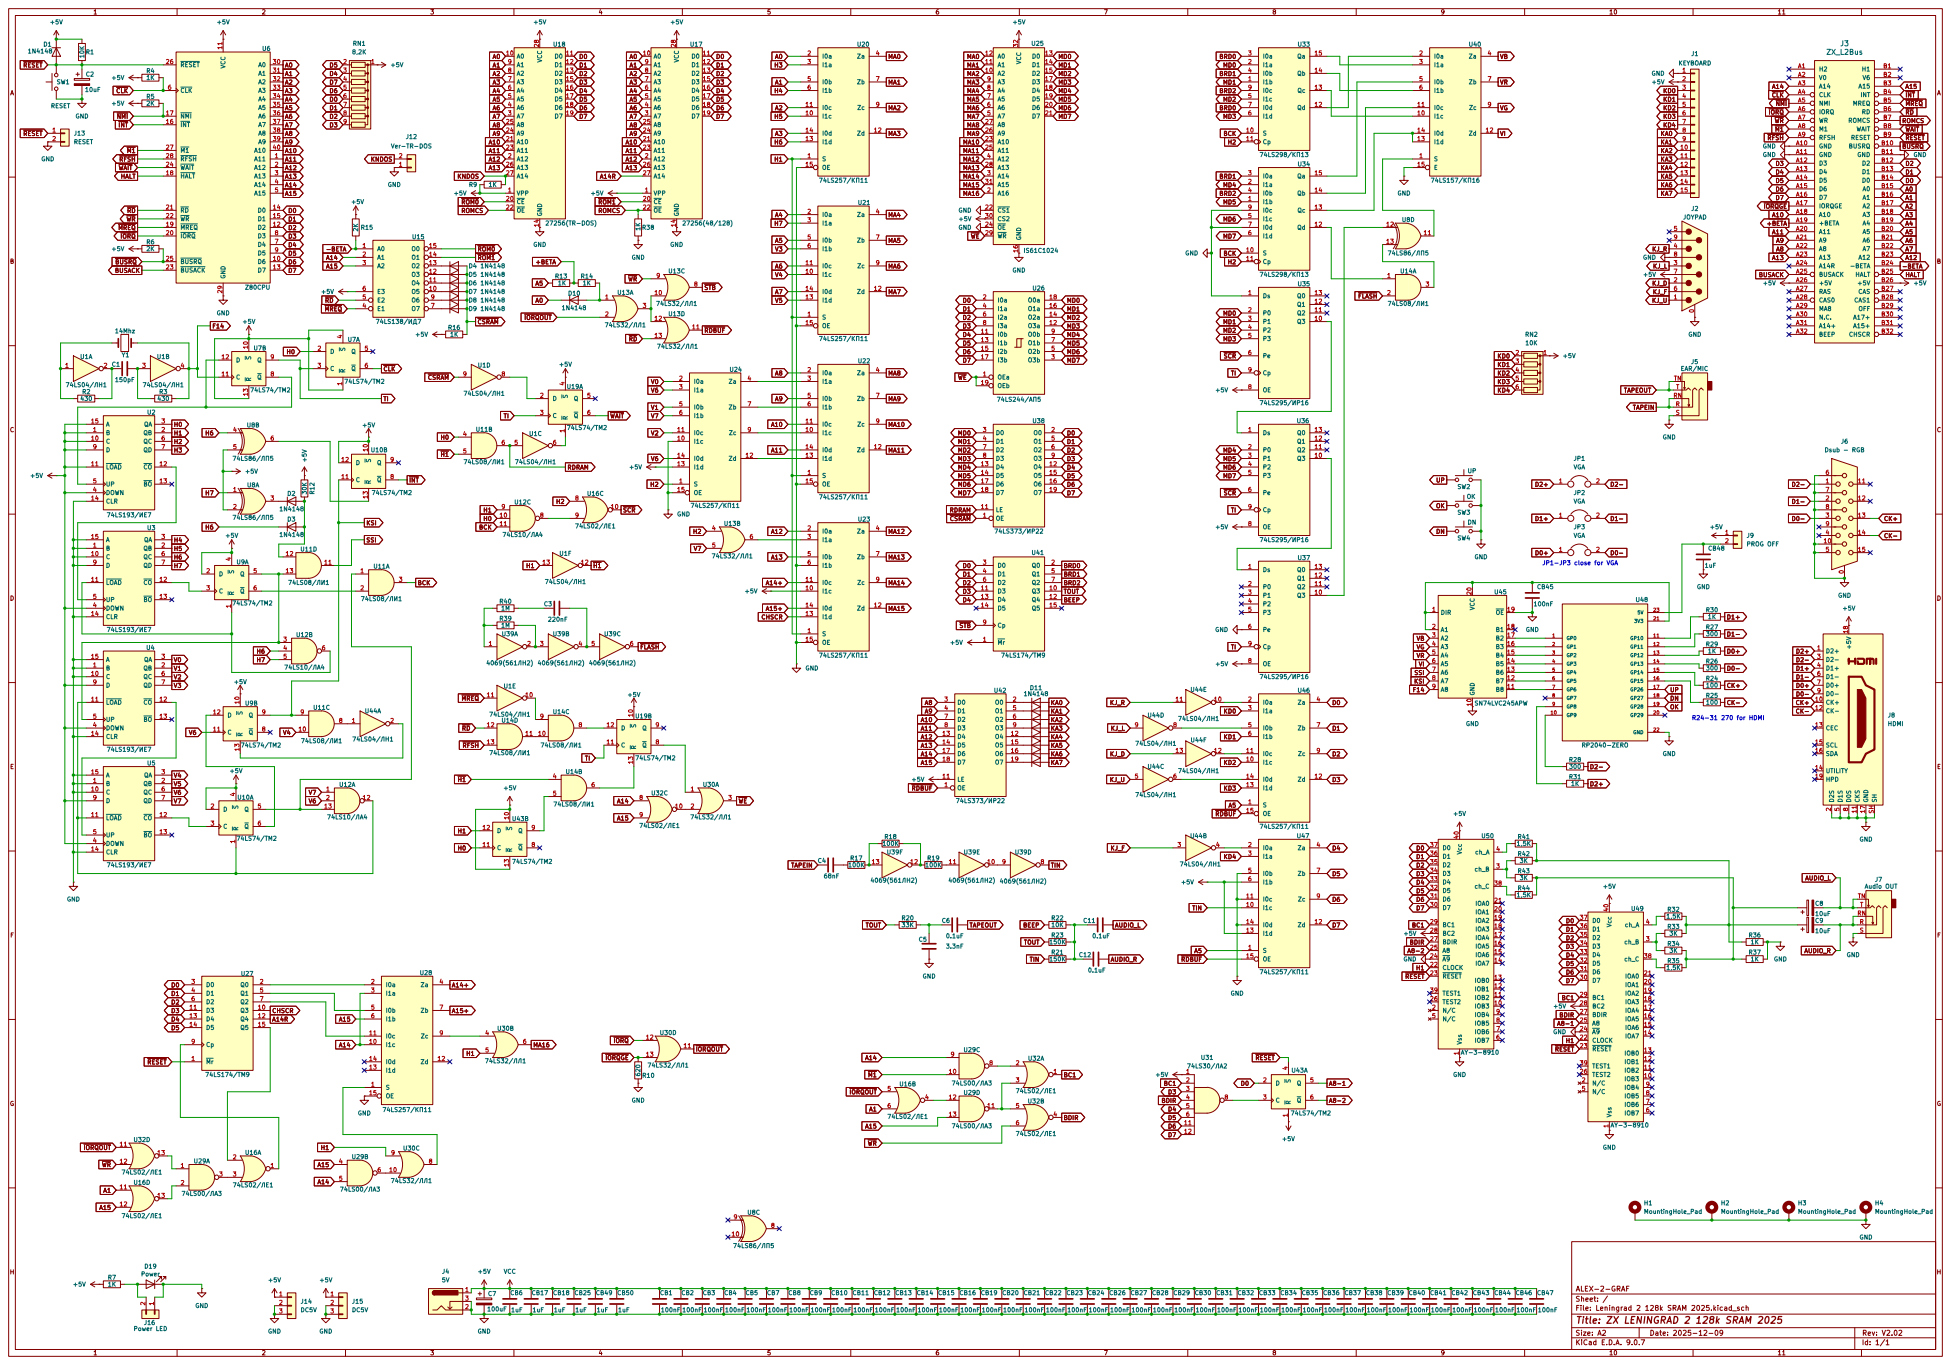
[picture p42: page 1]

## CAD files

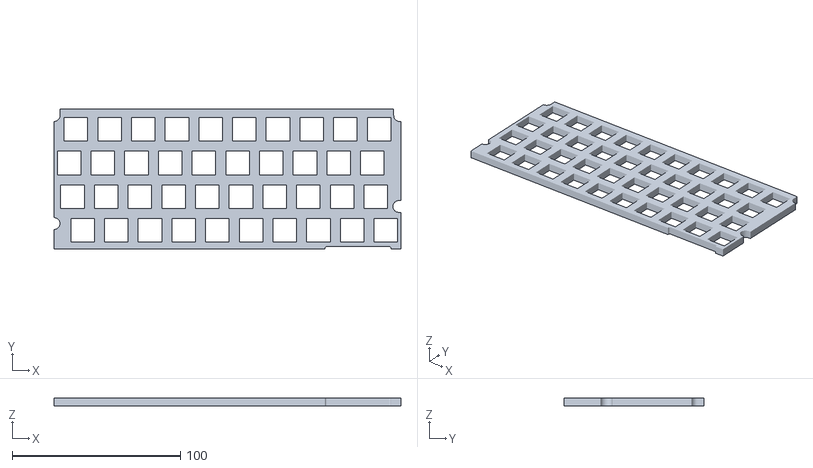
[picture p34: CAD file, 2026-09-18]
Export/AuroraKeys_small.stl
206.0 x 83.0 x 5.00

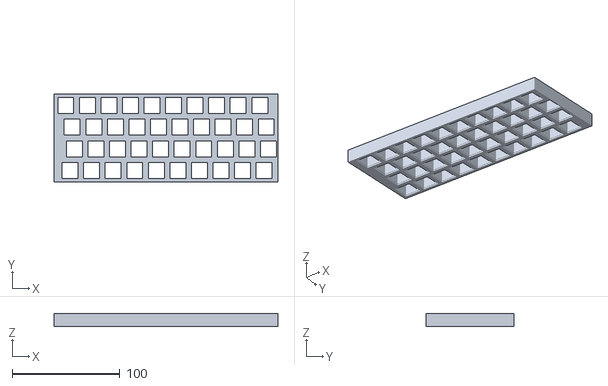
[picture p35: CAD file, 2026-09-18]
Export/KeyboardJig Alex2Graf.stl
207.8 x 81.8 x 12.0

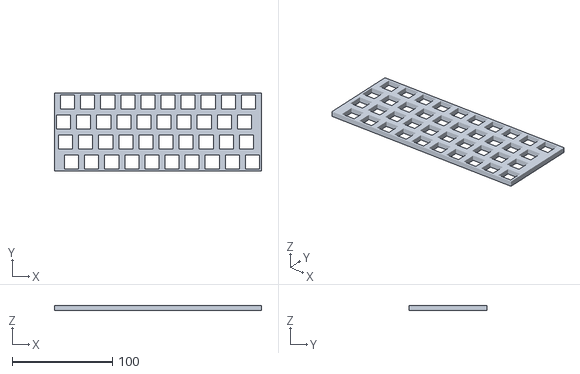
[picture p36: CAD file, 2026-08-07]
Export/AuroraKeys.stl
206.0 x 78.0 x 5.00
